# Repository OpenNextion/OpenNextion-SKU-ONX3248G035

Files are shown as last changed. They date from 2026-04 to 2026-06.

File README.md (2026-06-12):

[**English**](./README.md) | [简体中文](./README.zh-CN.md)

# ONX3248G035

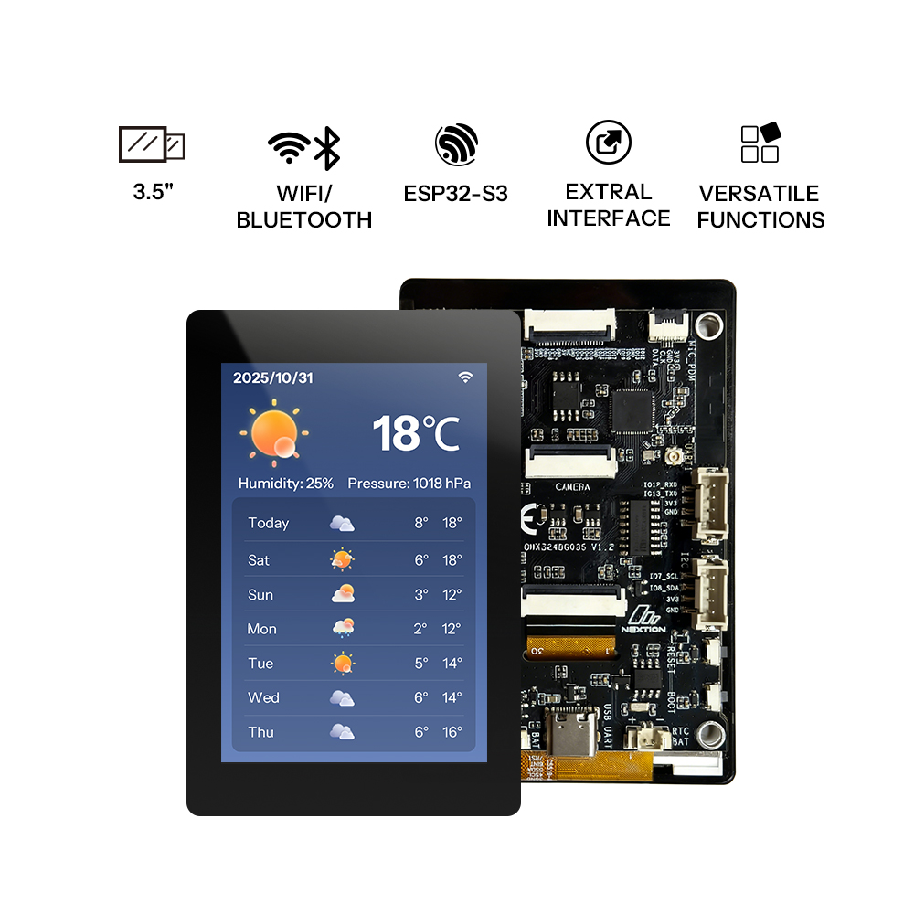
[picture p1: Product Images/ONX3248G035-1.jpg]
ONX3248G035


## Overview

`ONX3248G035` is a 3.5-inch Open Nextion HMI development board based on `ESP32-S3R8`. It integrates a capacitive touch display, `2.4 GHz Wi-Fi`, `Bluetooth 5 LE`, `MicroSD`, camera, microphone, speaker, battery management, and multiple expansion interfaces, making it suitable for HMI panels, IoT terminals, multimedia interaction, and rapid prototyping.

This repository collects product images, mechanical drawings, schematics, PCB files, certification documents, datasheets, USB-to-serial drivers, and example projects for this model. Both `ESP-IDF` and `ESP-Arduino` examples are provided so users can choose the development workflow that best fits their project.

## Purchase Links

- Product: [Open Nextion 3.5" Genius Series ESP32-S3 LCD Touchscreen Development Board](https://itead.cc/product/open-nextion-3-5-genius-series-esp32-s3-lcd-touchscreen-development-board/)
- Optional Audio Accessory: [Nextion BOX Speaker](https://itead.cc/product/nextion-box-speaker/)
- Optional Microphone Accessory: [Nextion Dual MIC Board](https://itead.cc/product/nextion-dual-mic-board/)
- Optional Expansion Accessory: [Nextion IO Adapter V2](https://itead.cc/product/nextion-io-adapter-v2/)

## Hardware Specifications

The following specifications are compiled from the official Wiki and the files included in this repository:

| Item | Specification |
| :--- | :--- |
| Model | `ONX3248G035` |
| MCU | `ESP32-S3R8`, Xtensa LX7 dual-core, up to `240 MHz` |
| Flash | `16 MB` |
| PSRAM | `8 MB` |
| Display Size | `3.5"` |
| Resolution | `320 x 480` |
| Colors | `262K` |
| Brightness | `300 nit` |
| Touch Type | Capacitive touch |
| LCD Driver | `ST7796` |
| Touch Driver | `CST826` |
| Wireless | `2.4 GHz Wi-Fi` + `Bluetooth 5 LE` |
| Power Input | `DC 5V/1A` |
| Battery Support | `3.7V` Li-ion battery interface with charging management, plus `3V` RTC backup battery support |
| Main Interfaces | `USB-C`, Grove `I2C`, Grove `UART1`, `MicroSD`, camera interface, PDM microphone interface, speaker interface, 24-pin GPIO, external antenna connector |
| Operating Temperature | `-20 to 70 C` |
| Storage Temperature | `-30 to 80 C` |
| Weight | Net weight about `61 g`, gross weight about `115 g` |

## Key Features

- Built on `ESP32-S3` for connected applications with graphical user interfaces.
- Onboard `3.5"` capacitive touch display, suitable for control panels, dashboards, and interactive terminals.
- Supports `MicroSD`, camera, `PDM` microphone, and speaker expansion for multimedia and voice-interaction projects.
- `USB-C` is used for power, firmware flashing, and serial logs, and supports automatic download mode.
- Includes an onboard antenna and a reserved external antenna connector for wireless applications.
- Supports Li-ion battery power and RTC backup battery, useful for portable devices and offline-clock scenarios.

## Repository Contents

| Folder | Description |
| :--- | :--- |
| `Certifications/` | Certification and compliance documents |
| `Datasheets/` | Datasheets for key components such as `ESP32-S3`, `ST7796`, `CST826`, `PCF8574`, and `IP4054V` |
| `Drawings/` | Mechanical dimension file, `2D` drawing, and `3D` model |
| `Example Programs/` | Example projects for both `ESP-IDF` and `ESP-Arduino` |
| `LTA Announcement/` | Official announcement document |
| `Product Images/` | Product photos |
| `Schematic & Layout /` | Schematics and PCB layout files |
| `USB-to-Serial Driver/` | USB-to-serial drivers for Windows, macOS, and Linux |

## Example Projects

`Example Programs/` contains two sets of ready-to-use examples:

- `ESP-IDF/`: native ESP-IDF projects, recommended for production firmware, component-based development, and full access to ESP-IDF features.
- `ESP-Arduino/`: Arduino sketches, recommended for quick prototyping, Arduino IDE users, and developers who prefer the ESP32 Arduino core.

Most example folders include both Chinese and English documentation.

### ESP-IDF Examples

| Example Folder | Description |
| :--- | :--- |
| `01_touch_test` | Touch test for LCD and touch verification |
| `02_music_test` | Play audio from `MicroSD` with touch interaction |
| `03_sd_card_image_test` | Read and display images from `MicroSD` |
| `04_sd_card_test` | `MicroSD` mount, read/write, and card info test |
| `05_wifi_test` | Wi-Fi scan, connection, and status display |
| `06_camera_test` | Connect an `OV2640` camera and preview the image on screen |
| `07_microphone_test` | PDM microphone capture, speech front-end processing, and playback |
| `08_battery_test` | Battery voltage, battery level estimation, and charge status display |
| `09_outofbox_demo` | Factory demo for quickly verifying LCD, touch, and LVGL UI |

### ESP-Arduino Examples

`Example Programs/ESP-Arduino/` contains Arduino versions of the board examples. Each folder can be opened directly in Arduino IDE through its `.ino` file.

| Example Folder | Description |
| :--- | :--- |
| `01_touch_test` | LCD, CST826 touch, PCF8574 reset, and LVGL touch-coordinate display test |
| `02_music_test` | Play `.mp3` files from `/music` on `MicroSD` with the LVGL music UI and speaker output |
| `03_sd_card_image_test` | Scan and display `JPG`, `JPEG`, and `PNG` images from `MicroSD` |
| `04_sd_card_test` | `MicroSD` mount, write, read, and verification test using `SD_MMC` |
| `05_wifi_test` | Wi-Fi scanning and connection UI using the ESP32 Arduino `WiFi` library |
| `06_camera_test` | `OV2640` camera capture and live LCD preview |
| `07_microphone_test` | PDM microphone recording and I2S speaker playback |
| `08_battery_test` | Battery voltage sampling, capacity estimation, and charging-state display |
| `09_outofbox_demo` | Arduino port of the factory LVGL widgets demo |

## Quick Start

### 1. Install the Driver

If your computer does not recognize the serial device, install the appropriate driver from `USB-to-Serial Driver/`:

- Windows: `CH340K-USB-to-UART-Driver.zip`
- macOS: `CH341SER_MAC.ZIP`
- Linux: `CH341SER_LINUX.zip`

### 2. Connect the Board

Use a `USB-C` cable to connect the board to your computer. The `USB-C` port can be used for:

- Power supply
- Firmware flashing
- Serial log output

### 3. Choose an Example

Go to `Example Programs/ESP-IDF/` or `Example Programs/ESP-Arduino/` and select the example you need. Check the included `README_zh.md` or `README_en.md` in each example folder and prepare the required peripherals, such as a `MicroSD` card, camera, microphone, or speaker.

### 4. Set Up the Development Environment

For `ESP-IDF`, the included examples indicate:

- Development version: `ESP-IDF 5.4.1`
- Recommended version: `ESP-IDF >= 5.4.0`

For `ESP-Arduino`, install the ESP32 Arduino core and the libraries required by the selected example. The common libraries are:

- `GFX Library for Arduino`
- `Adafruit CST8XX Library`
- `Adafruit PCF8574`
- `lvgl` 8.3.x

Some examples need additional libraries or built-in ESP32 Arduino features, such as `SD_MMC`, `WiFi`, `esp_camera`, ESP-IDF I2S drivers, or `ESP32-audioI2S-master`. See the example-specific README before compiling.

Recommended Arduino IDE settings for the larger examples, such as `02_music_test` and `09_outofbox_demo`:

- Board: `ESP32S3 Dev Module`
- Flash Size: `16MB (128Mb)`
- PSRAM: `OPI PSRAM`
- Partition Scheme: `16M Flash (3MB APP/9.9MB FATFS)`

### 5. Build and Flash with ESP-IDF

Example using the out-of-box demo:

```bash
cd "Example Programs/ESP-IDF/09_outofbox_demo"
idf.py set-target esp32s3
idf.py build
idf.py -p <PORT> flash monitor
```

If flashing fails on the first attempt, hold the `BOOT` button and press `RESET` once to enter download mode, then try again.

### 6. Build and Upload with Arduino

Open the target `.ino` file in Arduino IDE, select an ESP32-S3 board, choose the flash and PSRAM settings, then compile and upload. The same settings can also be supplied through `arduino-cli`. Example:

```bash
arduino-cli compile --fqbn esp32:esp32:esp32s3:FlashSize=16M,PartitionScheme=app3M_fat9M_16MB,PSRAM=opi "Example Programs/ESP-Arduino/09_outofbox_demo"
arduino-cli upload --fqbn esp32:esp32:esp32s3:FlashSize=16M,PartitionScheme=app3M_fat9M_16MB,PSRAM=opi -p <PORT> "Example Programs/ESP-Arduino/09_outofbox_demo"
```

## Notes

- `USB_UART` and `UART0` share the same `TX/RX` signals and cannot be used at the same time.
- The 24-pin GPIO expansion shares signals with `UART1`, `MIC_PDM`, and `CAMERA`, so check pin multiplexing before use.
- `USB-C` supports automatic download mode, while `UART0` does not.
- Wi-Fi supports `2.4 GHz` only.
- The speaker interface supports up to `2W`.
- If you need an external antenna, follow the official hardware instruction to switch the RF path by desoldering the corresponding resistor.
- The board itself is not waterproof. If needed, use a custom enclosure.
- For mechanical dimensions, see `Drawings/ONX3248G035-Dimension.pdf`.
- For detailed circuit design, see the files under `Schematic & Layout /`.

## References

- Official product page: [ONX3248G035 Wiki](https://nextion.tech/wiki/onx3248g035/)
- ESP-IDF getting started: [ESP32-S3 Getting Started](https://docs.espressif.com/projects/esp-idf/en/stable/esp32s3/get-started/)

If you are starting development on this board, it is recommended to begin with `09_outofbox_demo` or `01_touch_test` to verify the screen, touch, and basic environment first, then move on to `Wi-Fi`, `MicroSD`, camera, or audio-related features. Use `ESP-IDF` when you need the complete Espressif framework, and use `ESP-Arduino` when you want a faster Arduino-style starting point.

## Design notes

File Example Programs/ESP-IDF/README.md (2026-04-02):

# ESP32S3-NEXTION-EXAMPLE

This directory contains example projects for the ESP32-S3 development board (ONX3248G035), covering peripherals such as LCD touch, camera, audio, SD card, Wi-Fi, and battery. For details of each example, see the README in the corresponding example folder.

## Purchase Links

- Product: [Open Nextion 3.5" Genius Series ESP32-S3 LCD Touchscreen Development Board](https://itead.cc/product/open-nextion-3-5-genius-series-esp32-s3-lcd-touchscreen-development-board/)
- Optional Audio Accessory: [Nextion BOX Speaker](https://itead.cc/product/nextion-box-speaker/)
- Optional Microphone Accessory: [Nextion Dual MIC Board](https://itead.cc/product/nextion-dual-mic-board/)
- Optional Expansion Accessory: [Nextion IO Adapter V2](https://itead.cc/product/nextion-io-adapter-v2/)

> Note: This project was developed with ESP-IDF 5.4.1. It is recommended to use ESP-IDF version >= 5.4.0

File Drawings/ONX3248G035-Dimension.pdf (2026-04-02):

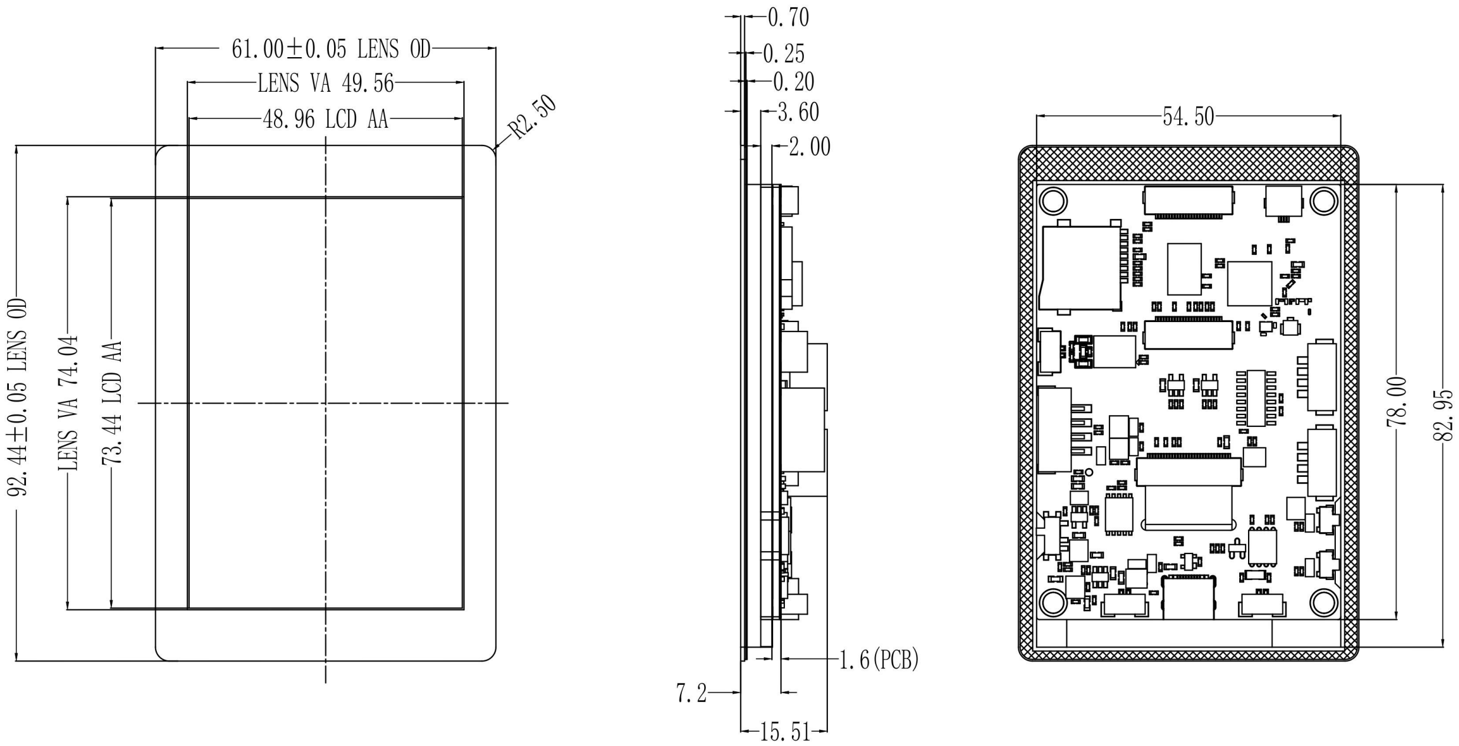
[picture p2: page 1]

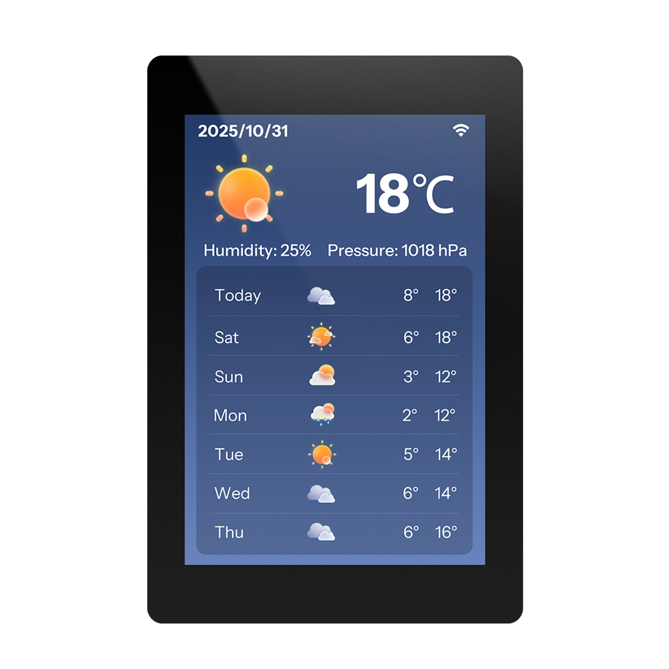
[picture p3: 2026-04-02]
Product Images/ONX3248G035-2.jpg

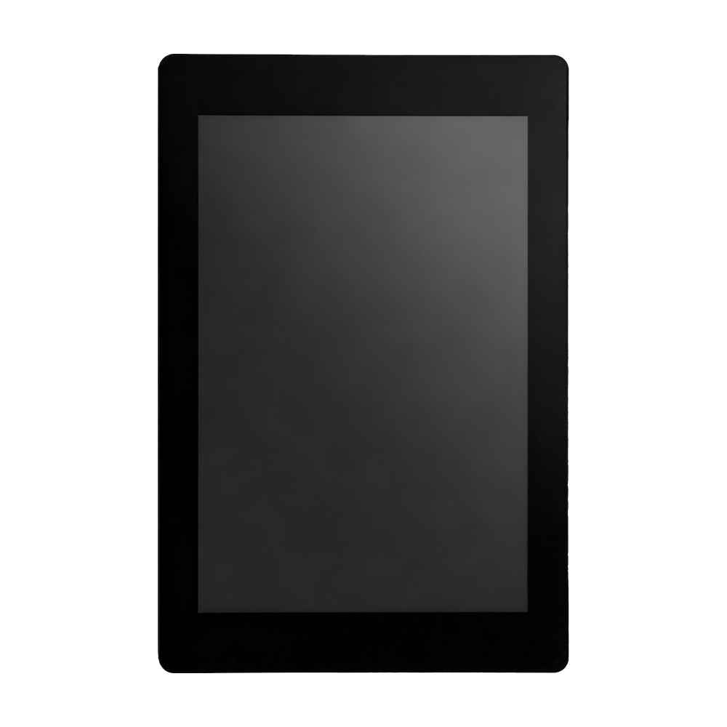
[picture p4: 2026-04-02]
Product Images/ONX3248G035-5.jpg

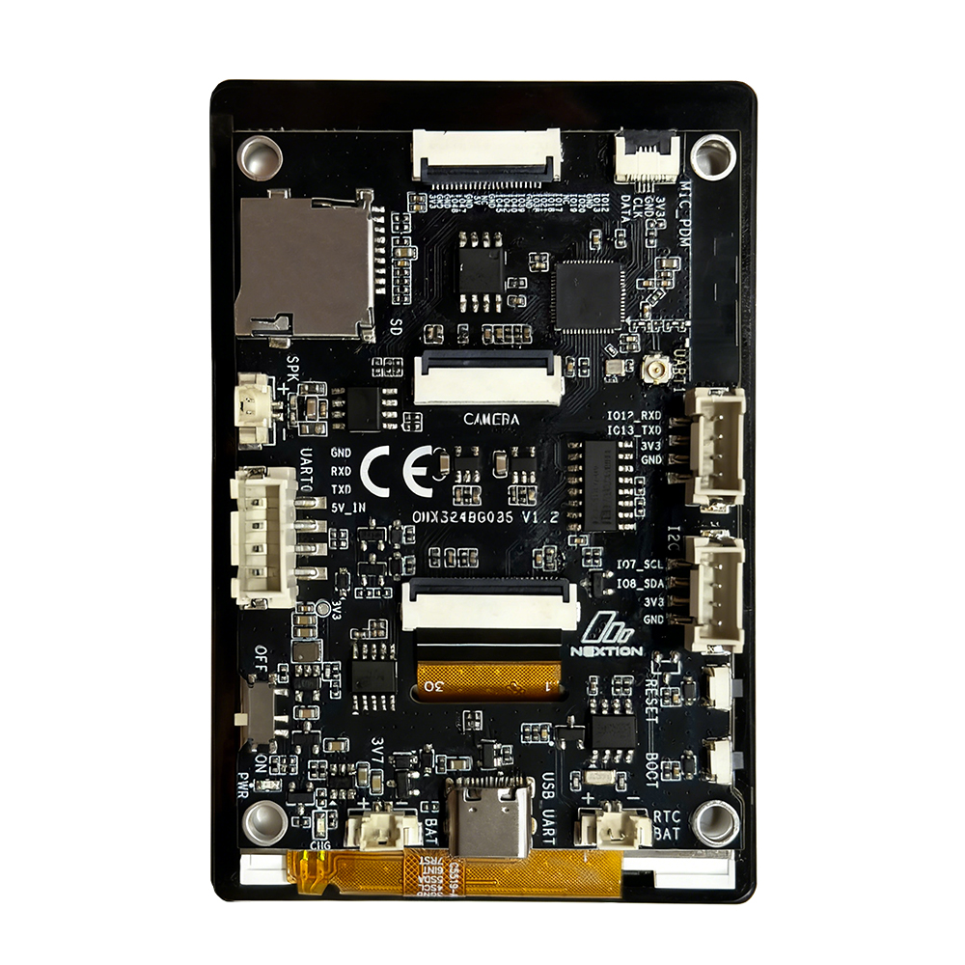
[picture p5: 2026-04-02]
Product Images/ONX3248G035-3.jpg

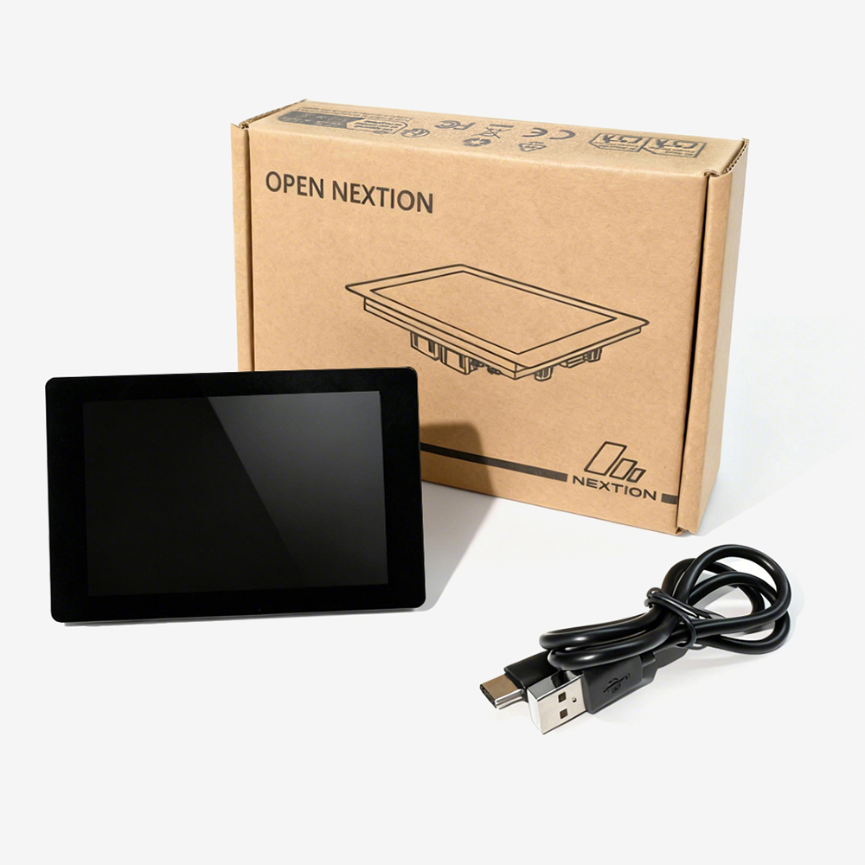
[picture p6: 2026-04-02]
Product Images/ONX3248G035-4.jpg

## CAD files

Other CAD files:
Drawings/ONX3248G035_2D_File.dwg

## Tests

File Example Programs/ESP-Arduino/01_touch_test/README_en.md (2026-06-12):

# ESP32-S3 Arduino Touch Test Example

## Overview

This is the ESP-Arduino version of `01_touch_test` for the ONX3248G035 3.5-inch display board. It uses standard Arduino libraries for the hardware drivers and LVGL for UI rendering:

- LCD: `Arduino_ST7796` from `GFX Library for Arduino`
- Touch: `Adafruit CST8XX Library`
- IO expander: `Adafruit PCF8574`
- UI: `lvgl`

The screen shows a white background and a gray `Touch Test` label. When the panel is touched, the sketch draws a red 4x4 pixel square at the touch position and prints the touch coordinates to the serial monitor.

LVGL renders the UI text. The touch trail follows the ESP-IDF example approach: it draws 4x4 red blocks directly through the LCD driver, avoiding unbounded LVGL object creation during long touch tests.

## Files

- `01_touch_test.ino`: Main sketch, directly openable in Arduino IDE.
- `BoardConfig.h`: Board pins, resolution, and I2C addresses.
- `build_opt.h`: Arduino ESP32 build options used to make LVGL use its built-in default configuration.

## Hardware Pins

| Function | ESP32-S3 Pin |
| :--- | :--- |
| I2C SCL | GPIO7 |
| I2C SDA | GPIO8 |
| LCD SCLK | GPIO5 |
| LCD MOSI | GPIO1 |
| LCD DC | GPIO3 |
| LCD CS | GPIO2 |
| LCD BL | GPIO6 |
| LCD RST | PCF8574 P6 |

## Arduino IDE Setup

1. Install the ESP32 Arduino core.
2. Install these libraries: `GFX Library for Arduino`, `Adafruit CST8XX Library`, `Adafruit PCF8574`, and `lvgl`.
3. Open `ESP-Arduino/01_touch_test/01_touch_test.ino`.
4. Select an ESP32-S3 board.
5. Recommended settings:
   - USB CDC On Boot: Enabled
   - PSRAM: Enabled
   - Flash Size: select the option that matches the module
6. Compile and upload.
7. Open the serial monitor at 115200 baud to view touch coordinates.

## Display Direction

The display direction can be configured at the top of `01_touch_test.ino`:

```cpp
#define DISPLAY_SWAP_XY false
#define DISPLAY_MIRROR_X true
#define DISPLAY_MIRROR_Y false
```

The default values match the ESP-IDF example direction configuration.

## Implementation Notes

- LCD reset is controlled by PCF8574 P6. Other expander pins are kept high during reset to avoid disturbing shared peripherals.
- LVGL renders the initial UI and label. Root-screen scrolling is disabled so edge touches do not drag the page.
- Touch dots are drawn directly with `Arduino_GFX`, similar to the ESP-IDF example's `esp_lcd_panel_draw_bitmap()` path.

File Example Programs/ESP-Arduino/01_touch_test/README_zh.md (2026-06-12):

# ESP32-S3 Arduino 触摸测试示例

## 概述

本示例是 `01_touch_test` 的 ESP-Arduino 版本，用于 ONX3248G035 开发板的 3.5 寸屏基础触摸测试。程序使用 Arduino 标准库生态完成硬件驱动和 UI 绘制：

- LCD：`GFX Library for Arduino` 的 `Arduino_ST7796`
- 触摸：`Adafruit CST8XX Library`
- IO 扩展：`Adafruit PCF8574`
- UI：`lvgl`

屏幕显示白色背景和灰色 `Touch Test` 文本。触摸屏幕时，程序会在触点位置绘制红色 4x4 像素方块，并在串口监视器输出触摸坐标。

UI 文本由 LVGL 绘制；触摸轨迹参考 ESP-IDF 例程的实现方式，使用 LCD 驱动直接刷 4x4 红色小块，避免连续触摸时创建大量 LVGL 对象导致内存增长。

## 文件

- `01_touch_test.ino`: Arduino IDE 可直接打开的主程序。
- `BoardConfig.h`: 板级引脚、分辨率和 I2C 地址配置。
- `build_opt.h`: Arduino ESP32 编译选项，用于让 LVGL 使用内置默认配置。

## 硬件引脚

| 功能 | ESP32-S3 引脚 |
| :--- | :--- |
| I2C SCL | GPIO7 |
| I2C SDA | GPIO8 |
| LCD SCLK | GPIO5 |
| LCD MOSI | GPIO1 |
| LCD DC | GPIO3 |
| LCD CS | GPIO2 |
| LCD BL | GPIO6 |
| LCD RST | PCF8574 P6 |

## Arduino IDE 设置

1. 安装 ESP32 Arduino core。
2. 安装库：`GFX Library for Arduino`、`Adafruit CST8XX Library`、`Adafruit PCF8574`、`lvgl`。
3. 打开 `ESP-Arduino/01_touch_test/01_touch_test.ino`。
4. 开发板选择 ESP32-S3 类型的开发板。
5. 建议设置：
   - USB CDC On Boot: Enabled
   - PSRAM: Enabled
   - Flash Size: 按实际模组选项选择
6. 编译并烧录。
7. 打开 115200 波特率串口监视器查看触摸坐标。

## 屏幕方向

屏幕方向可在 `01_touch_test.ino` 顶部通过以下宏配置：

```cpp
#define DISPLAY_SWAP_XY false
#define DISPLAY_MIRROR_X true
#define DISPLAY_MIRROR_Y false
```

当前默认值与 ESP-IDF 例程中的方向配置保持一致。

## 实现说明

- LCD 复位通过 PCF8574 P6 控制，初始化时保持其它扩展 IO 为高电平，避免影响共用扩展 IO 的外设。
- LVGL 负责初始界面和文字显示，根页面禁用滚动，避免触摸边缘时页面被拖动。
- 红点使用 `Arduino_GFX` 直接刷屏绘制，行为接近 ESP-IDF 例程中的 `esp_lcd_panel_draw_bitmap()`。

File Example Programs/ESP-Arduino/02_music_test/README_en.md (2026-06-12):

# ESP32-S3 Arduino Music Test Example

## Overview

This is the ESP-Arduino version of `02_music_test` for the ONX3248G035 board.

It uses standard Arduino/ESP32 libraries and third-party libraries:

- LCD: `Arduino_ST7796` from `GFX Library for Arduino`
- Touch: `Adafruit CST8XX Library`
- IO expander: `Adafruit PCF8574`
- SD card: `SD_MMC` from the ESP32 Arduino core
- UI: `lvgl`, with the Music Demo UI assets ported from the ESP-IDF `components/gui`
- Audio playback: `ESP32-audioI2S-master`

The sketch mounts the SD card, scans `/music` for `.mp3` files, and displays the same LVGL Music Demo style as the ESP-IDF example: cover art, spectrum, track metadata, playback controls, and the ALL TRACKS list. Tapping a track plays it through the onboard NS4168 speaker amplifier.

## Notes

This Arduino version matches the ESP-IDF UI and uses a proven third-party library for MP3 decoding and I2S playback. It does not implement a custom audio decoder.

## Audio And Pop Suppression

- I2S BCLK: GPIO14
- I2S LRCLK/WS: GPIO16
- I2S DOUT/SDATA: GPIO15
- NS4168 enable: PCF8574 `I2S_CTRL`

PCF8574 ports default high after power-up. If `I2S_CTRL` is enabled too early, the speaker may pop before I2S output is stable. This sketch keeps `I2S_CTRL=LOW` during initialization and enables the amplifier only after MP3 decoding and I2S output have started. It also disables the amplifier during pause and track switching.

## ESP32S3R8 + 16 MB Flash Settings

This sketch ports the complete LVGL Music UI images and fonts from the ESP-IDF example, so it is larger than Arduino's default `1.2 MB APP` partition. For ESP32S3R8 with external 16 MB flash, use these Arduino IDE settings:

- Board: `ESP32S3 Dev Module`
- Flash Size: `16MB (128Mb)`
- PSRAM: `OPI PSRAM`
- Partition Scheme: `16M Flash (3MB APP/9.9MB FATFS)`

The project includes `sketch.yaml` as a record of the target board settings. With the current Arduino CLI, `--profile` may skip the locally installed library search path, so use the verified full FQBN:

```bash
arduino-cli compile --fqbn esp32:esp32:esp32s3:FlashSize=16M,PartitionScheme=app3M_fat9M_16MB,PSRAM=opi ESP-Arduino/02_music_test
arduino-cli upload --fqbn esp32:esp32:esp32s3:FlashSize=16M,PartitionScheme=app3M_fat9M_16MB,PSRAM=opi -p <your port> ESP-Arduino/02_music_test
```

## Files

- `02_music_test.ino`: Main Arduino sketch.
- `BoardConfig.h`: Board pins, resolution, I2C addresses, SD pins, and I2S pins.
- `build_opt.h`: LVGL build option.
- `sketch.yaml`: Target board setting record for ESP32S3R8 + 16 MB flash.
- `src/gui`: LVGL Music UI source and assets ported from the ESP-IDF example.
- `src/gui/gui_hal.cpp`: Arduino adapter for SD_MMC scanning, MP3 playback, volume mapping, and amplifier timing.

## SD Card Layout

Create this folder in the SD card root:

```text
/music
```

Then copy `.mp3` files into it.

## Dependencies

Install these libraries from Arduino IDE Library Manager:

- `GFX Library for Arduino`
- `Adafruit CST8XX Library`
- `Adafruit PCF8574`
- `lvgl` 8.3.x
- `ESP32-audioI2S-master`

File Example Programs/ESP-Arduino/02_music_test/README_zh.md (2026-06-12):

# ESP32-S3 Arduino 音乐测试示例

## 概述

本示例是 `02_music_test` 的 ESP-Arduino 版本，用于 ONX3248G035 开发板的基础音乐文件测试。

程序使用标准 Arduino/ESP32 库和第三方库：

- LCD：`GFX Library for Arduino` 的 `Arduino_ST7796`
- 触摸：`Adafruit CST8XX Library`
- IO 扩展：`Adafruit PCF8574`
- SD 卡：ESP32 Arduino core 的 `SD_MMC`
- UI：`lvgl`，并移植 ESP-IDF 版本 `components/gui` 的 Music Demo 界面资源
- 音频播放：`ESP32-audioI2S-master`

示例会挂载 SD 卡，扫描 `/music` 目录中的 `.mp3` 文件，并使用与 ESP-IDF 版本同源的 LVGL Music Demo UI 显示封面、波形、曲目信息、播放控制和 ALL TRACKS 列表。点击曲目后会通过 I2S 输出到板载 NS4168 喇叭功放。

## 说明

当前 Arduino 版本已对齐 ESP-IDF 版本的 UI 效果，并使用成熟第三方库完成 MP3 解码和 I2S 播放，没有自写音频解码器。

## 音频与防爆破声

- I2S BCLK: GPIO14
- I2S LRCLK/WS: GPIO16
- I2S DOUT/SDATA: GPIO15
- NS4168 使能：PCF8574 `I2S_CTRL`

PCF8574 上电默认端口为高电平，若过早打开 `I2S_CTRL`，喇叭可能在 I2S 输出稳定前产生瞬间爆破声。本例程在初始化时保持 `I2S_CTRL=LOW`，只有在 MP3 解码和 I2S 输出启动后延迟打开功放；暂停或切歌时也会先关闭功放。

## ESP32S3R8 + 16MB Flash 配置

本例程移植了 ESP-IDF 版本的完整 LVGL Music UI 图片和字体资源，程序体积超过 Arduino 默认 `1.2MB APP` 分区。你的硬件为 ESP32S3R8 + 外挂 16MB Flash，请在 Arduino IDE 中选择：

- Board: `ESP32S3 Dev Module`
- Flash Size: `16MB (128Mb)`
- PSRAM: `OPI PSRAM`
- Partition Scheme: `16M Flash (3MB APP/9.9MB FATFS)`

工程内提供了 `sketch.yaml` 记录目标配置。当前 Arduino CLI 版本使用 `--profile` 时可能不加载本机已安装库路径，推荐使用已验证的完整 FQBN：

```bash
arduino-cli compile --fqbn esp32:esp32:esp32s3:FlashSize=16M,PartitionScheme=app3M_fat9M_16MB,PSRAM=opi ESP-Arduino/02_music_test
arduino-cli upload --fqbn esp32:esp32:esp32s3:FlashSize=16M,PartitionScheme=app3M_fat9M_16MB,PSRAM=opi -p <你的串口> ESP-Arduino/02_music_test
```

## 文件

- `02_music_test.ino`: Arduino 主程序。
- `BoardConfig.h`: 板级引脚、分辨率、I2C 地址和 SD/I2S 引脚配置。
- `build_opt.h`: LVGL 编译选项。
- `sketch.yaml`: ESP32S3R8 + 16MB Flash 的目标配置记录。
- `src/gui`: 从 ESP-IDF 版本移植的 LVGL Music UI 源码和资源。
- `src/gui/gui_hal.cpp`: Arduino 适配层，负责 SD_MMC 扫描、MP3 播放、音量映射和功放时序控制。

## SD 卡目录

请在 SD 卡根目录创建：

```text
/music
```

并放入 `.mp3` 文件。

## 依赖库

请在 Arduino IDE 的 Library Manager 中安装：

- `GFX Library for Arduino`
- `Adafruit CST8XX Library`
- `Adafruit PCF8574`
- `lvgl` 8.3.x
- `ESP32-audioI2S-master`

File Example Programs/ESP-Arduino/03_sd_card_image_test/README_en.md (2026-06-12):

# ESP32-S3 Arduino SD Card Image Test Example

## Overview

This is the ESP-Arduino version of `03_sd_card_image_test`. It tests SD-card image-file scanning and full-screen image browsing.

Libraries used:

- LCD: `GFX Library for Arduino`
- Touch: `Adafruit CST8XX Library`
- IO expander: `Adafruit PCF8574`
- SD card: `SD_MMC` from the ESP32 Arduino core
- UI: `lvgl`
- JPG/JPEG decoding: Espressif JPEG decoder bundled with the ESP32 Arduino core
- PNG decoding: LVGL bundled `lodepng`

The sketch scans `/images` for image files. When images are found, it opens a full-screen image viewer. Swipe left/right to switch to the previous or next image.

## Notes

This version does not implement a custom image decoder. JPG/JPEG files are decoded with `esp_jpeg_decode()` from the ESP32 Arduino core, and PNG files are decoded with LVGL's bundled `lodepng`. Images are fully decoded into a PSRAM frame buffer before the LCD is updated in bands, which avoids visible top-to-bottom decode refresh on the panel.

Images use a fixed width-fit policy: regardless of the source orientation, the image is scaled to the 320-pixel screen width and vertically centered. Other extensions are scanned for compatibility with the ESP-IDF directory rules, but the current Arduino version directly renders JPG/JPEG/PNG only; unsupported formats show a decode-failed message.

`build_opt.h` enables `LV_USE_PNG` and `LV_MEM_CUSTOM` so LVGL builds PNG support and the PNG decoder can allocate from the configured external-memory path.

## SD Card Layout

Create this folder in the SD card root:

```text
/images
```

Then copy image files into it.

Recommended formats:

```text
.jpg
.jpeg
.png
```

## Arduino IDE Settings

When opening this example in Arduino IDE, use:

- Board: `ESP32S3 Dev Module`
- Flash Size: `16MB (128Mb)`
- PSRAM: `OPI PSRAM`
- Partition Scheme: `16M Flash (3MB APP/9.9MB FATFS)`

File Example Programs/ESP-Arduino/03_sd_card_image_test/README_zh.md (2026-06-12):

# ESP32-S3 Arduino SD 卡图片测试示例

## 概述

本示例是 `03_sd_card_image_test` 的 ESP-Arduino 版本，用于测试 SD 卡图片文件扫描和全屏图片浏览。

使用的库：

- LCD：`GFX Library for Arduino`
- 触摸：`Adafruit CST8XX Library`
- IO 扩展：`Adafruit PCF8574`
- SD 卡：ESP32 Arduino core 的 `SD_MMC`
- UI：`lvgl`
- JPG/JPEG 解码：ESP32 Arduino core 内置的 Espressif JPEG decoder
- PNG 解码：LVGL 内置 `lodepng`

程序会扫描 SD 卡 `/images` 目录中的图片文件。找到图片后会进入全屏图片浏览界面，左右滑动切换上一张/下一张。

## 说明

当前版本不自写图片解码器，JPG/JPEG 使用 ESP32 Arduino core 提供的 `esp_jpeg_decode()`，PNG 使用 LVGL 自带的 `lodepng`。图片会先完整解码到 PSRAM 帧缓冲，再一次性分段刷新到 LCD，避免屏幕出现明显的从上到下解码刷新过程。

图片显示策略为固定宽度适配：无论图片原始方向如何，都会按屏幕宽度缩放到 320 像素宽，并在垂直方向居中显示。其他扩展名会参与扫描以兼容 ESP-IDF 版本的目录规则，但 Arduino 版本当前只直接渲染 JPG/JPEG/PNG；遇到暂未支持的格式时屏幕会显示解码失败提示。

`build_opt.h` 中启用了 `LV_USE_PNG` 和 `LV_MEM_CUSTOM`，用于让 LVGL 编译 PNG 支持，并让 PNG 解码输出使用可用的外部内存配置。

## SD 卡目录

请在 SD 卡根目录创建：

```text
/images
```

并放入图片文件。

推荐优先放入：

```text
.jpg
.jpeg
.png
```

## Arduino IDE 设置

使用 Arduino IDE 打开本例程时，开发板建议选择：

- Board: `ESP32S3 Dev Module`
- Flash Size: `16MB (128Mb)`
- PSRAM: `OPI PSRAM`
- Partition Scheme: `16M Flash (3MB APP/9.9MB FATFS)`

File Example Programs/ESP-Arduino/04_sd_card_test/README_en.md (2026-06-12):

# ESP32-S3 Arduino SD Card Test Example

## Overview

This is the ESP-Arduino version of `04_sd_card_test`. It tests SD-card mounting, writing, reading, and verification.

Libraries used:

- LCD: `GFX Library for Arduino`
- Touch: `Adafruit CST8XX Library`
- IO expander: `Adafruit PCF8574`
- SD card: `SD_MMC` from the ESP32 Arduino core
- UI: `lvgl`

After tapping the `SD CARD TEST` button, the sketch re-detects and mounts the SD card, writes `/SD CARD TEST.txt` to the SD card root, reads it back, and compares the content. It shows `WRITE SUCCESS` when the readback matches, `NO SD CARD DETECTED` when no card is present, and an error message for other read/write failures.

## Test Flow

1. Initialize the LCD, CST826 touch controller, PCF8574 IO expander, and LVGL.
2. Tap the `SD CARD TEST` button.
3. Release the previous `SD_MMC` mount state and mount the SD card again.
4. Write a random string to `/SD CARD TEST.txt`.
5. Close the file, reopen it, and read the content back.
6. Compare the written and readback strings, then show the result on screen.

With this flow, removing the SD card after one successful test is handled on the next tap and shows `NO SD CARD DETECTED`.

## SD Card Notes

- The sketch uses `SD_MMC` from the ESP32 Arduino core in 1-bit mode.
- `/SD CARD TEST.txt` is created or overwritten in the SD card root.
- The file content is similar to `SD CARD TEST RAND NUM 12345678` and changes on every tap.

## Arduino IDE Settings

When opening this example in Arduino IDE, use:

- Board: `ESP32S3 Dev Module`
- Flash Size: `16MB (128Mb)`
- PSRAM: `OPI PSRAM`
- Partition Scheme: `16M Flash (3MB APP/9.9MB FATFS)`

## Files

- `04_sd_card_test.ino`: Main Arduino sketch.
- `BoardConfig.h`: Board pins, resolution, and SD-card pins.
- `build_opt.h`: LVGL build option; it currently skips the default `lv_conf.h`.

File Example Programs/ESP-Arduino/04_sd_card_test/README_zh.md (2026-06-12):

# ESP32-S3 Arduino SD 卡读写测试示例

## 概述

本示例是 `04_sd_card_test` 的 ESP-Arduino 版本，用于测试 SD 卡挂载、写入、读回和校验。

使用的库：

- LCD：`GFX Library for Arduino`
- 触摸：`Adafruit CST8XX Library`
- IO 扩展：`Adafruit PCF8574`
- SD 卡：ESP32 Arduino core 的 `SD_MMC`
- UI：`lvgl`

点击屏幕上的 `SD CARD TEST` 按钮后，程序会先重新检测并挂载 SD 卡，然后向 SD 卡根目录写入 `/SD CARD TEST.txt`，再读回内容并比较。如果一致，显示 `WRITE SUCCESS`；如果未检测到 SD 卡，显示 `NO SD CARD DETECTED`；其他读写异常显示错误信息。

## 测试流程

1. 初始化 LCD、CST826 触摸、PCF8574 IO 扩展和 LVGL。
2. 点击 `SD CARD TEST` 按钮。
3. 释放上一次的 `SD_MMC` 挂载状态，并重新挂载 SD 卡。
4. 写入随机字符串到 `/SD CARD TEST.txt`。
5. 关闭文件后重新打开并读回内容。
6. 比较写入和读回内容，并在屏幕上显示测试结果。

这样处理后，插卡测试成功后再拔卡，下一次点击会重新检测 SD 卡并显示 `NO SD CARD DETECTED`。

## SD 卡说明

- 使用 ESP32 Arduino core 的 `SD_MMC`，配置为 1-bit 模式。
- SD 卡根目录会生成或覆盖 `/SD CARD TEST.txt`。
- 测试文件内容类似 `SD CARD TEST RAND NUM 12345678`，每次点击都会更新。

## Arduino IDE 设置

使用 Arduino IDE 打开本例程时，开发板建议选择：

- Board: `ESP32S3 Dev Module`
- Flash Size: `16MB (128Mb)`
- PSRAM: `OPI PSRAM`
- Partition Scheme: `16M Flash (3MB APP/9.9MB FATFS)`

## 文件

- `04_sd_card_test.ino`: Arduino 主程序。
- `BoardConfig.h`: 板级引脚、分辨率和 SD 卡引脚配置。
- `build_opt.h`: LVGL 编译选项，当前仅跳过默认 `lv_conf.h`。

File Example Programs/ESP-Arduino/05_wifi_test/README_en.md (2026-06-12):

# ESP32-S3 Arduino WiFi Test Example

## Overview

This is the ESP-Arduino version of `05_wifi_test`. It tests WiFi scanning and a basic connection UI.

Libraries used:

- LCD: `GFX Library for Arduino`
- Touch: `Adafruit CST8XX Library`
- IO expander: `Adafruit PCF8574`
- WiFi: `WiFi` from the ESP32 Arduino core
- UI: `lvgl`

Tap `Scan` to scan nearby WiFi APs. The list shows SSID, RSSI, and encryption state. Tap an AP to open the password panel, then tap `Connect` to start the connection attempt.

## Implementation

WiFi scanning and connection use the standard ESP32 Arduino `WiFi.h` APIs. No custom WiFi manager stack is implemented.

## Operation Flow

1. Power on and enter the WiFi Test page.
2. Tap `Scan` in the top-right corner. The sketch switches to STA mode and scans nearby APs.
3. The list shows up to 20 APs. Each item includes SSID, RSSI, and `open` / `secure` state.
4. Tap an AP to open the password panel.
5. Tap the password field to show LVGL's built-in keyboard.
6. Enter the password and tap `Connect` to start connecting.
7. When connected, the status label shows the SSID and IP address. Failed or disconnected states are also shown.

## Notes

- This example demonstrates scanning and basic connection only; WiFi credentials are not saved.
- For open networks, tap the AP and then tap `Connect` with an empty password field.
- The sketch calls `WiFi.disconnect(true)` before scanning so scan results and connection state are refreshed.

## Arduino IDE Settings

When opening this example in Arduino IDE, use:

- Board: `ESP32S3 Dev Module`
- Flash Size: `16MB (128Mb)`
- PSRAM: `OPI PSRAM`
- Partition Scheme: `16M Flash (3MB APP/9.9MB FATFS)`

## Files

- `05_wifi_test.ino`: Main Arduino sketch.
- `BoardConfig.h`: Board pins, resolution, touch, and LCD configuration.
- `build_opt.h`: LVGL build option; it currently skips the default `lv_conf.h`.

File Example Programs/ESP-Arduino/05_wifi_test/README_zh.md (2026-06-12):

# ESP32-S3 Arduino WiFi 测试示例

## 概述

本示例是 `05_wifi_test` 的 ESP-Arduino 版本，用于测试 WiFi 扫描和基础连接 UI。

使用的库：

- LCD：`GFX Library for Arduino`
- 触摸：`Adafruit CST8XX Library`
- IO 扩展：`Adafruit PCF8574`
- WiFi：ESP32 Arduino core 的 `WiFi`
- UI：`lvgl`

点击 `Scan` 按钮后，程序会扫描附近 WiFi AP，并显示 SSID、RSSI 和加密状态。点击某个 AP 后会弹出密码输入框，输入密码并点击 `Connect` 可尝试连接。

## 说明

WiFi 扫描和连接使用 ESP32 Arduino core 的标准 `WiFi.h`，没有自写 WiFi 管理栈。

## 操作流程

1. 上电后进入 WiFi Test 页面。
2. 点击右上角 `Scan`，程序切换到 STA 模式并扫描附近 AP。
3. 列表最多显示 20 个 AP，每一项包含 SSID、RSSI 和 `open` / `secure` 状态。
4. 点击 AP 后弹出密码输入面板。
5. 点击密码输入框会显示 LVGL 内置键盘。
6. 输入密码并点击 `Connect` 后开始连接。
7. 连接成功时显示当前 SSID 和 IP 地址；连接失败或断开时显示对应状态。

## 注意事项

- 本例程只演示扫描和基础连接，不保存 WiFi 配置。
- 开放网络可直接点击 AP 后点击 `Connect`，密码框可以留空。
- 扫描前会调用 `WiFi.disconnect(true)`，用于刷新扫描结果和连接状态。

## Arduino IDE 设置

使用 Arduino IDE 打开本例程时，开发板建议选择：

- Board: `ESP32S3 Dev Module`
- Flash Size: `16MB (128Mb)`
- PSRAM: `OPI PSRAM`
- Partition Scheme: `16M Flash (3MB APP/9.9MB FATFS)`

## 文件

- `05_wifi_test.ino`: Arduino 主程序。
- `BoardConfig.h`: 板级引脚、分辨率和触摸/LCD 配置。
- `build_opt.h`: LVGL 编译选项，当前仅跳过默认 `lv_conf.h`。

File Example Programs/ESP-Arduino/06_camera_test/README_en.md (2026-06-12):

# ESP32-S3 Arduino Camera Test Example

## Overview

This is the ESP-Arduino version of `06_camera_test`. It tests camera capture and live LCD preview on the ONX3248G035 board.

Libraries used:

- LCD: `GFX Library for Arduino`
- Touch: `Adafruit CST8XX Library`
- IO expander: `Adafruit PCF8574`
- UI: `lvgl`
- Camera: `esp_camera` from the ESP32 Arduino core

## Features

- ST7796U display through Arduino_GFX.
- CST826 touch through Adafruit CST8XX.
- LVGL title and status label.
- RGB565/QVGA camera capture through the ESP32 Arduino core camera driver.
- Camera frames are pushed directly to the LCD preview area with Arduino_GFX to reduce per-frame copies.

## Runtime Flow

1. Initialize I2C, PCF8574, LCD, backlight, and touch.
2. Pull camera `PWDN` low through PCF8574 to wake the camera module.
3. Initialize `esp_camera` with QVGA `320x240` and `RGB565` output.
4. Draw the `Camera Test` title and status text with LVGL.
5. In the main loop, capture one frame about every 80 ms and draw it in the middle of the screen.

## Camera Configuration

- Frame size: `FRAMESIZE_QVGA`
- Resolution: `320x240`
- Pixel format: `PIXFORMAT_RGB565`
- XCLK: `20 MHz`
- Uses two frame buffers when PSRAM is available; otherwise falls back to one DRAM frame buffer.

This example matches the ESP-IDF behavior: after boot, it continuously displays the camera preview and does not provide a pause/resume button.

## Arduino IDE Settings

When opening this example in Arduino IDE, use:

- Board: `ESP32S3 Dev Module`
- Flash Size: `16MB (128Mb)`
- PSRAM: `OPI PSRAM`
- Partition Scheme: `16M Flash (3MB APP/9.9MB FATFS)`

## Files

- `06_camera_test.ino`: Main Arduino sketch.
- `BoardConfig.h`: LCD, touch, PCF8574, and camera pin configuration.
- `build_opt.h`: LVGL build option; it currently skips the default `lv_conf.h`.

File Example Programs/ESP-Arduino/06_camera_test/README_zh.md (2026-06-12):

# ESP32-S3 Arduino 摄像头测试示例

## 概述

本示例是 `06_camera_test` 的 ESP-Arduino 版本，用于测试 ONX3248G035 的摄像头采集和 LCD 实时预览。

使用的库：

- LCD：`GFX Library for Arduino`
- 触摸：`Adafruit CST8XX Library`
- IO 扩展：`Adafruit PCF8574`
- UI：`lvgl`
- 摄像头：ESP32 Arduino core 自带 `esp_camera`

## 功能

- 使用 Arduino_GFX 驱动 ST7796U LCD。
- 使用 Adafruit CST8XX 读取 CST826 触摸。
- 使用 LVGL 绘制标题和状态提示。
- 使用 ESP32 Arduino core 自带的 `esp_camera` 获取 RGB565/QVGA 图像。
- 摄像头帧通过 Arduino_GFX 直接刷新到屏幕预览区域，减少每帧复制。

## 运行流程

1. 初始化 I2C、PCF8574、LCD、背光和触摸。
2. 通过 PCF8574 拉低摄像头 `PWDN`，唤醒摄像头模组。
3. 初始化 `esp_camera`，配置为 QVGA `320x240`、`RGB565` 输出。
4. 使用 LVGL 绘制 `Camera Test` 标题和状态文本。
5. 主循环中约每 80 ms 获取一帧摄像头图像，并显示在屏幕中部。

## 摄像头配置

- 帧尺寸：`FRAMESIZE_QVGA`
- 分辨率：`320x240`
- 像素格式：`PIXFORMAT_RGB565`
- XCLK：`20 MHz`
- PSRAM 可用时使用 2 个帧缓冲；否则使用 1 个 DRAM 帧缓冲。

本例程行为与 ESP-IDF 版本保持一致：上电后持续显示摄像头预览，不提供暂停/恢复按钮。

## Arduino IDE 设置

使用 Arduino IDE 打开本例程时，开发板建议选择：

- Board: `ESP32S3 Dev Module`
- Flash Size: `16MB (128Mb)`
- PSRAM: `OPI PSRAM`
- Partition Scheme: `16M Flash (3MB APP/9.9MB FATFS)`

## 文件

- `06_camera_test.ino`: Arduino 主程序。
- `BoardConfig.h`: LCD、触摸、PCF8574 和摄像头引脚配置。
- `build_opt.h`: LVGL 编译选项，当前仅跳过默认 `lv_conf.h`。

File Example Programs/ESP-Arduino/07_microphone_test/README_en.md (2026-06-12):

# ESP32-S3 Arduino Microphone Record/Playback Example

## Overview

This is the ESP-Arduino version of `07_microphone_test`. It tests PDM microphone recording and speaker playback on the ONX3248G035 board.

The interaction matches the ESP-IDF example: press and hold `MIC` to record, release it to loop-play the audio stored in RAM, and tap `Stop` to stop recording or playback.

Libraries used:

- LCD: `GFX Library for Arduino`
- Touch: `Adafruit CST8XX Library`
- IO expander: `Adafruit PCF8574`
- UI: `lvgl`
- Microphone: ESP-IDF `driver/i2s_pdm.h` from the ESP32 Arduino core
- Speaker: ESP-IDF `driver/i2s_std.h` from the ESP32 Arduino core

## Runtime Flow

1. Initialize LCD, CST826 touch, PCF8574, PDM microphone input, and I2S speaker output.
2. Allocate a 30-second recording buffer from PSRAM.
3. Press and hold `MIC`: recording starts and the button turns red.
4. Release `MIC`: recording stops and loop playback starts; the button turns green.
5. Tap `Stop`: stop recording or playback and disable the speaker amplifier.

## Audio Configuration

- Sample rate: `16000 Hz`
- Bit depth: `16-bit`
- Recording format: PDM RX converted to PCM mono
- Playback format: I2S STD TX mono
- Maximum record time: `30 s`
- Record buffer: PSRAM first, internal RAM fallback

Note: the ESP-IDF version includes the ESP-SR/AFE processing chain. The Arduino version keeps the core record/playback behavior and uses the standard I2S drivers bundled with the ESP32 Arduino core instead of porting ESP-SR/AFE.

## Arduino IDE Settings

When opening this example in Arduino IDE, use:

- Board: `ESP32S3 Dev Module`
- Flash Size: `16MB (128Mb)`
- PSRAM: `OPI PSRAM`
- Partition Scheme: `16M Flash (3MB APP/9.9MB FATFS)`

## Files

- `07_microphone_test.ino`: Main Arduino sketch.
- `BoardConfig.h`: LCD, touch, PDM microphone, I2S speaker, and PCF8574 pin configuration.
- `build_opt.h`: LVGL build option; it currently skips the default `lv_conf.h`.

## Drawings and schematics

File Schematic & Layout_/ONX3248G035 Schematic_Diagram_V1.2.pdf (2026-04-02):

# SD CARD ESP32-S3

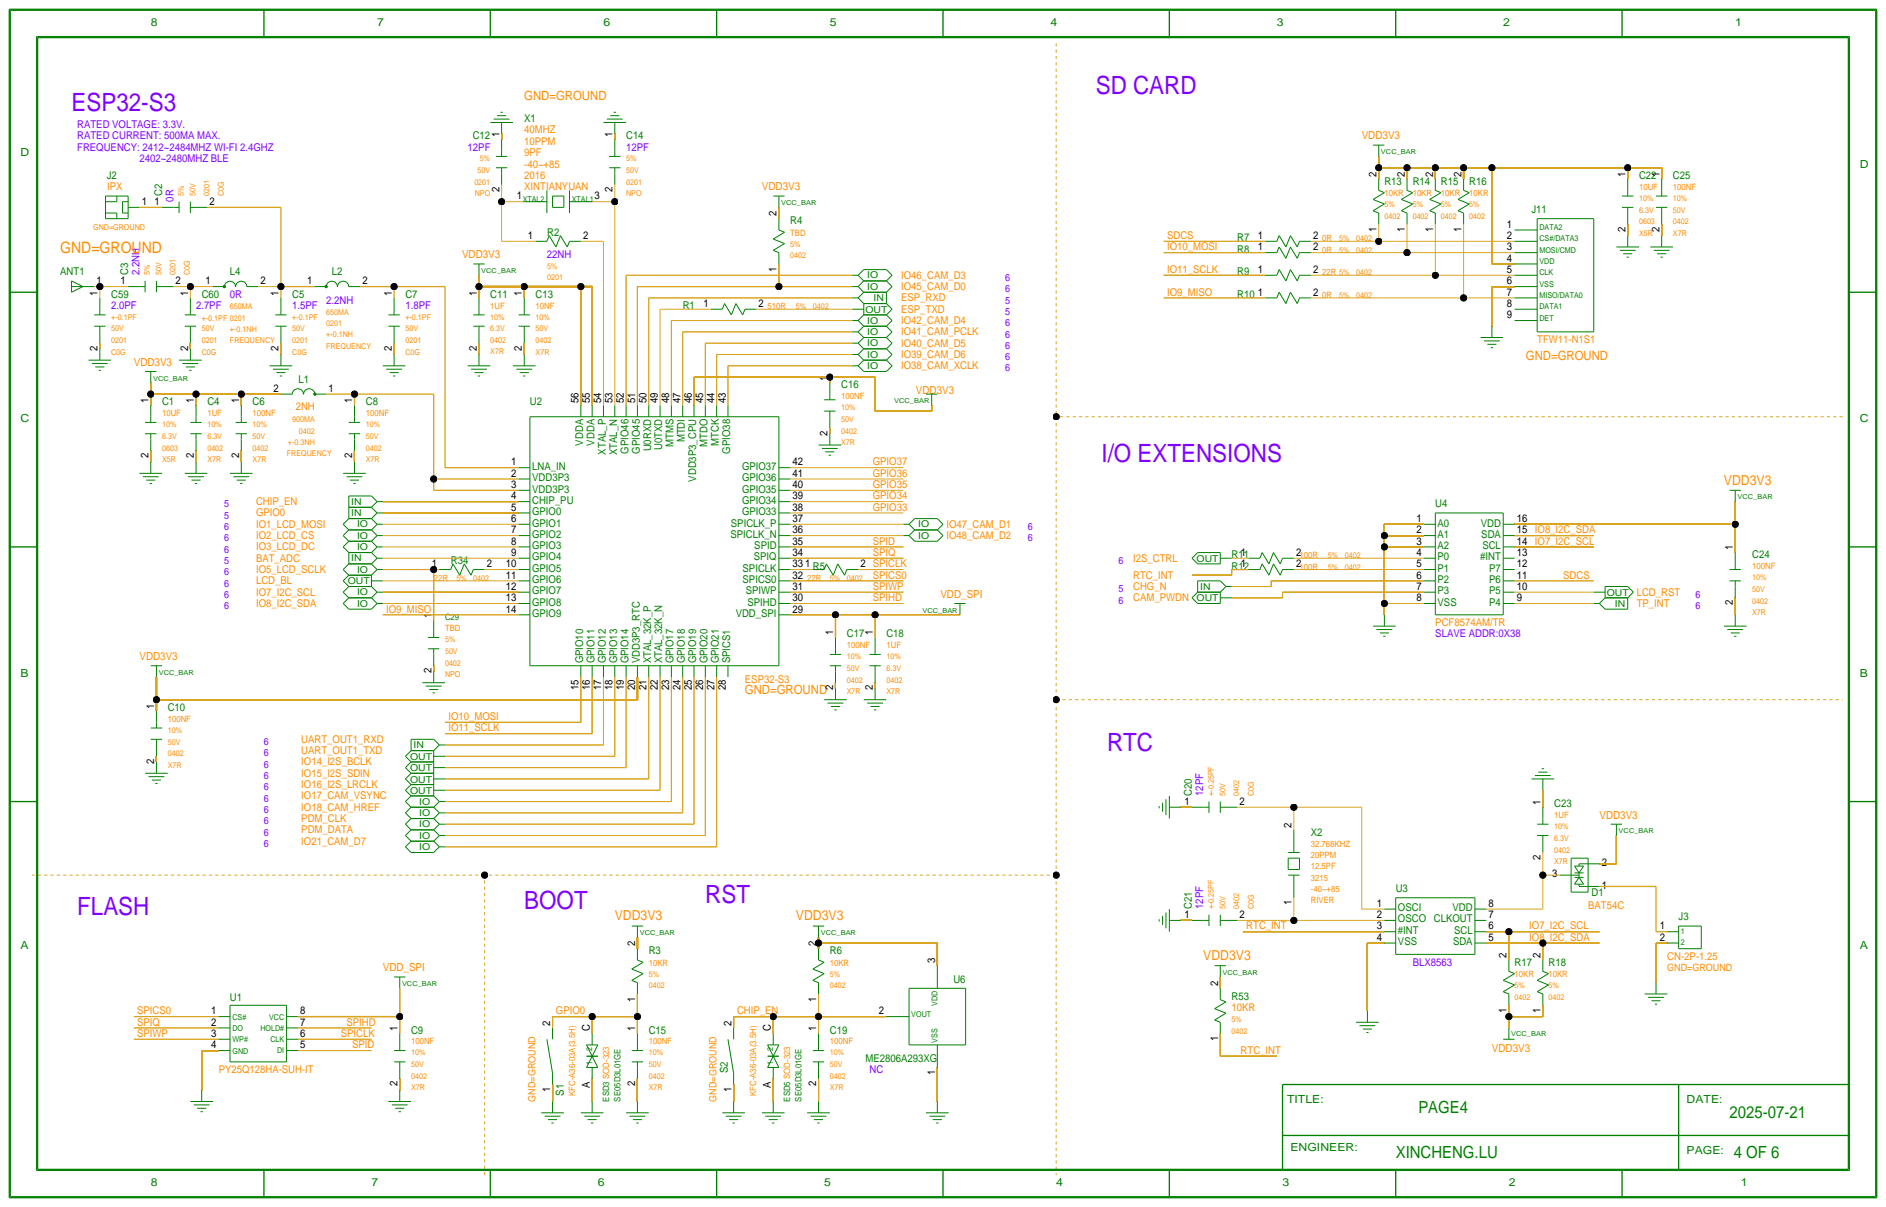
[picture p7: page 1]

2 2 | 15 15 IO8_I2C_SDA IO8_I2C_SDA
3 3 | 14 14 IO7_I2C_SCL IO7_I2C_SCL

TITLE: TITLE: PAGE4 PAGE4 | DATE: DATE: 2025-07-21 2025-07-21

ENGINEER: XINCHENG.LU | PAGE: 4 OF 6

POWER ON POWER ON VSYS VSYS VBUS VBUS | USB TO TTL / UART INPUT USB TO TTL / UART INPUT VBUS 1A VBUS 1A D3 D3 GND=GROUND GND=GROUND B5819WS B5819WS

### VBAT

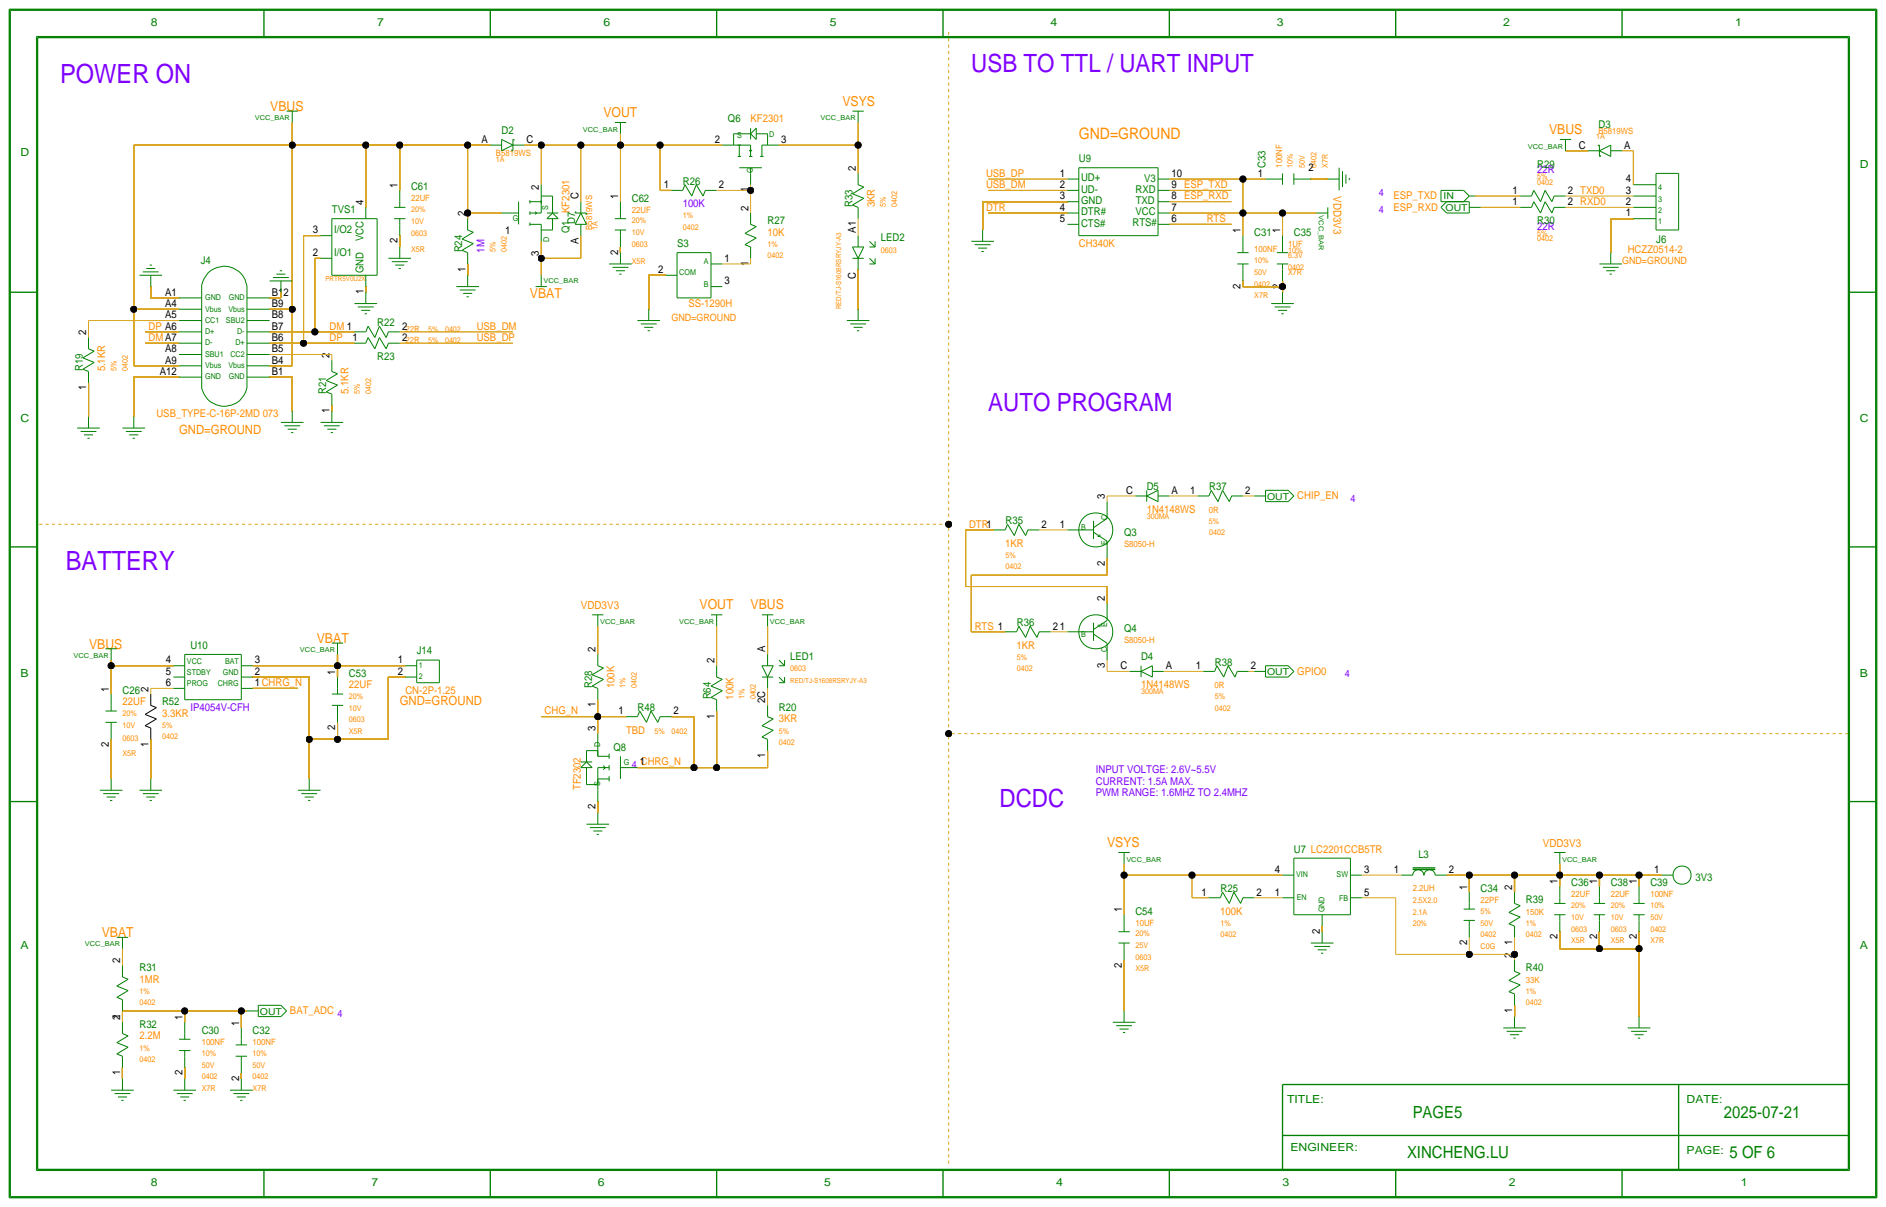
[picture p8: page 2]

TVS1

# LCD CAMERA

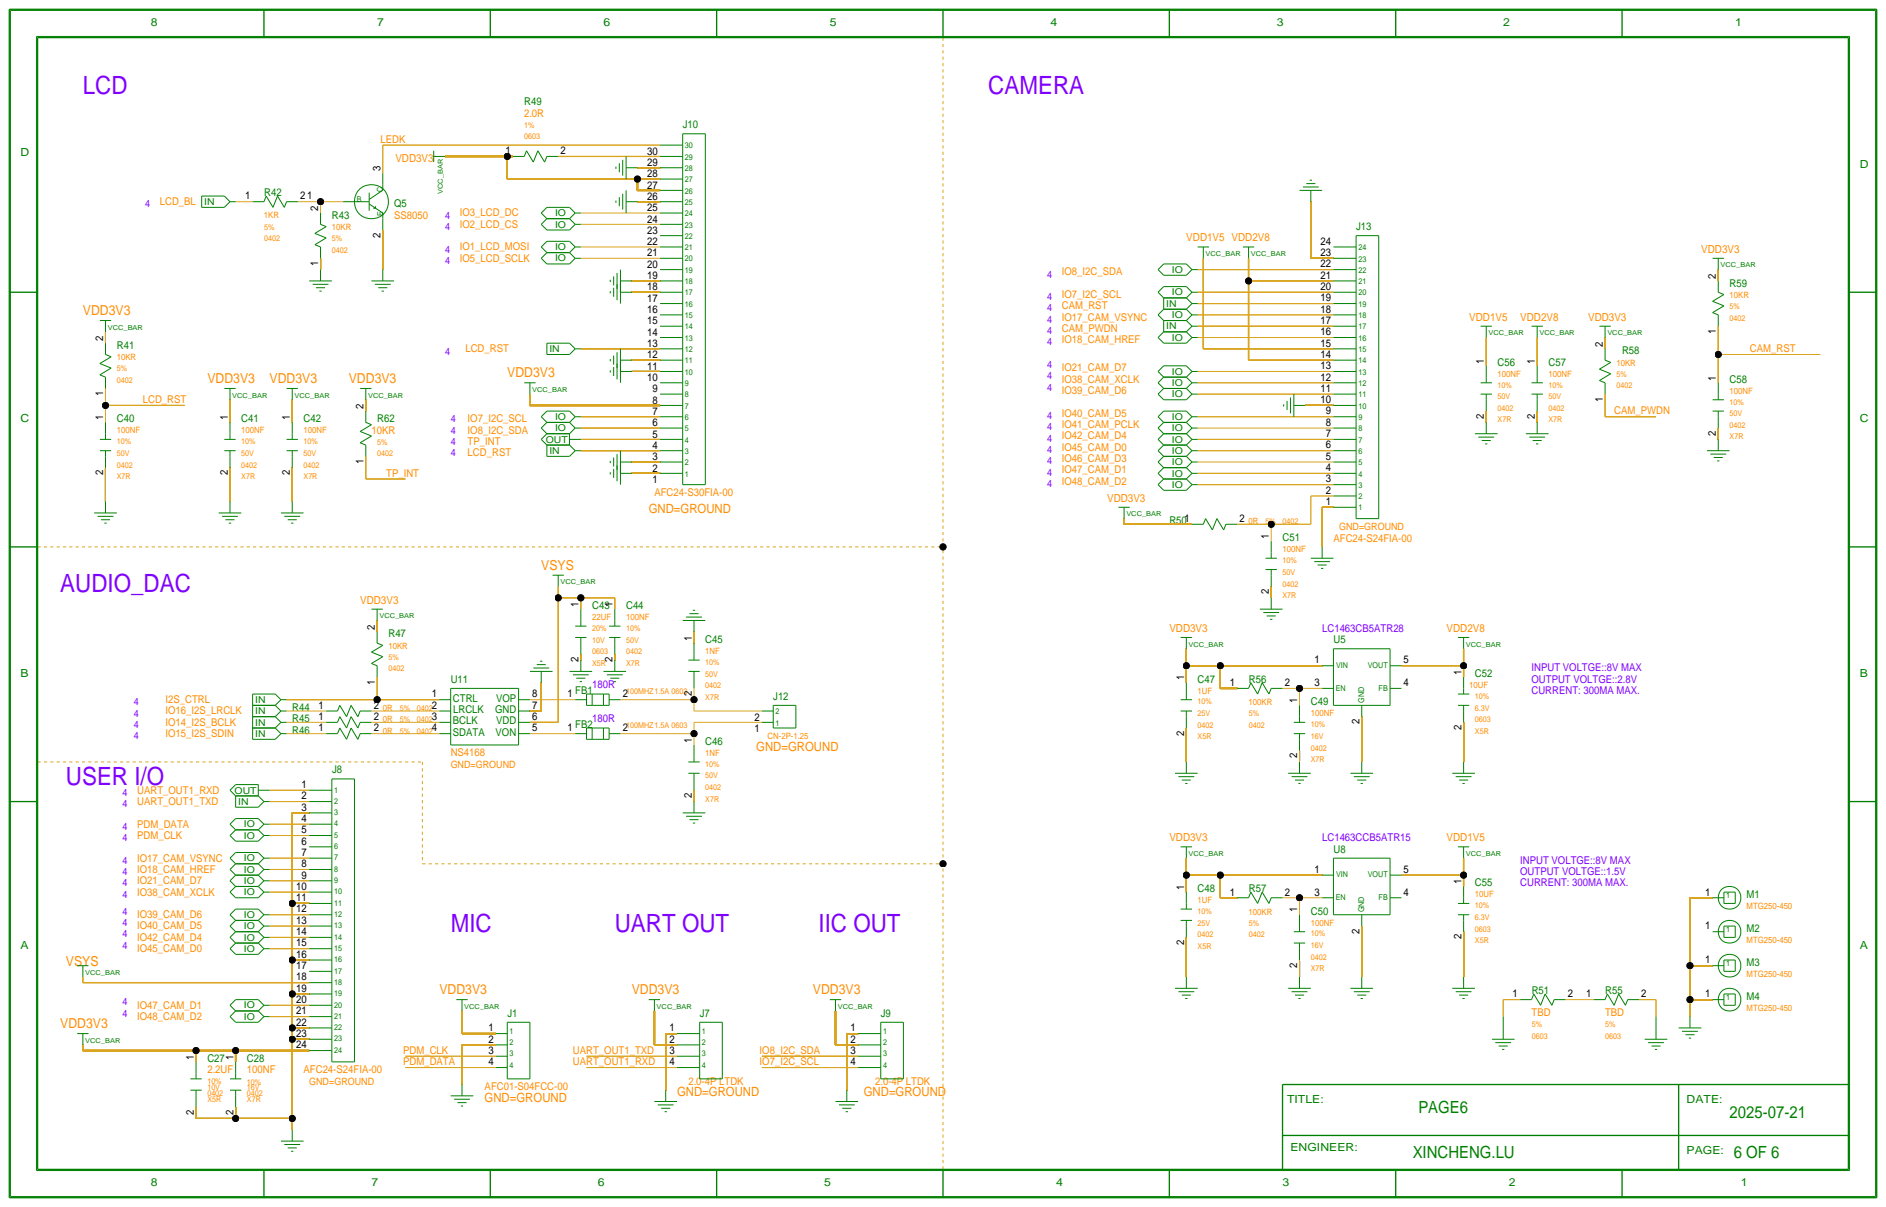
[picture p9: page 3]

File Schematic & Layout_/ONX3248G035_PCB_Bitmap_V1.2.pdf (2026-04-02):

## silkbottom

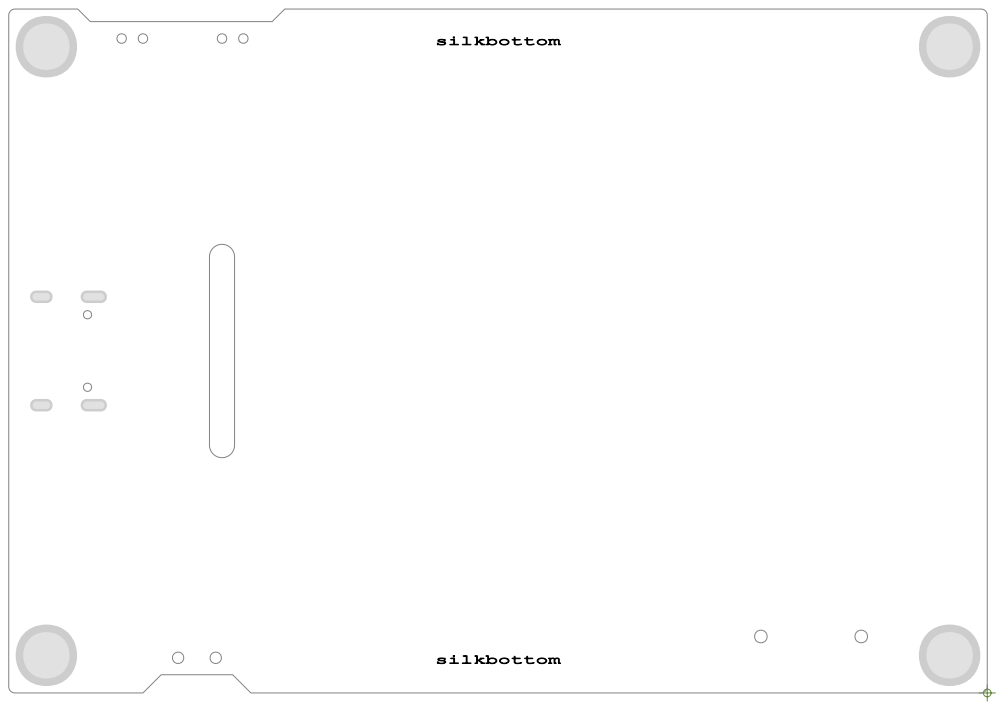
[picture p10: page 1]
silkbottom

## silktop

## CLK

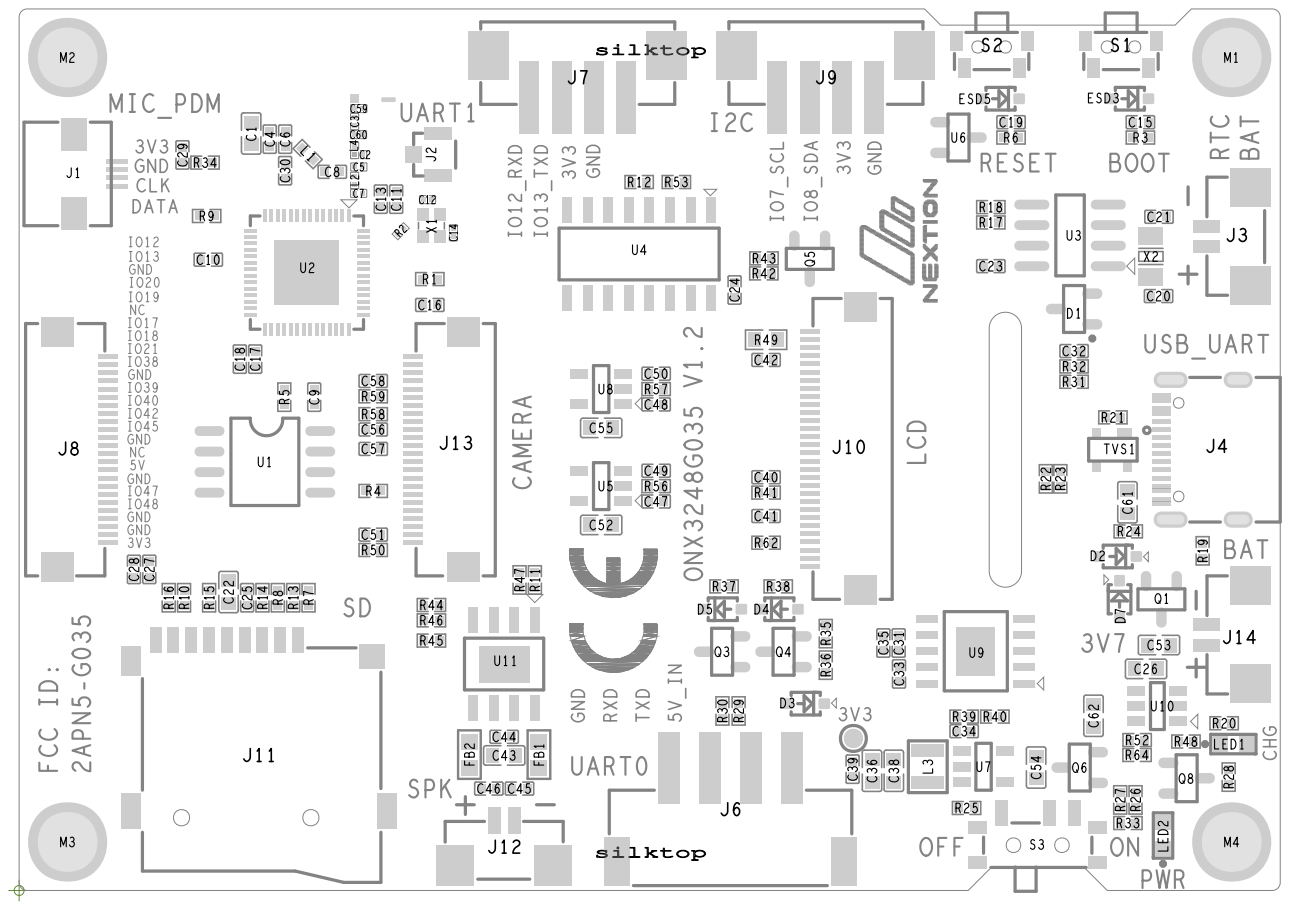
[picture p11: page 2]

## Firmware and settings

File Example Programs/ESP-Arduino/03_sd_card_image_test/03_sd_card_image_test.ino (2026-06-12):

#include <Arduino.h>
#include <Wire.h>
#include <SPI.h>
#include <SD_MMC.h>
#include <FS.h>
#include <Arduino_GFX_Library.h>
#include <Adafruit_CST8XX.h>
#include <Adafruit_PCF8574.h>
#include <jpeg_decoder.h>

#define LV_CONF_SKIP
#include <lvgl.h>
// Reuse LVGL's bundled lodepng implementation for PNG decoding. The Arduino
// sketch calls the C API directly, so the C++ wrappers are disabled here.
#define LODEPNG_NO_COMPILE_CPP
extern "C" {
#include <extra/libs/png/lodepng.h>
}

#include "BoardConfig.h"

static const uint32_t LCD_SPI_FREQ = 40000000;
static const uint16_t LVGL_BUF_LINES = 40;
static const char *IMAGE_DIR = "/images";
static const uint8_t MAX_IMAGES = 64;

// Keep the same direction macros as the touch example so the LCD and CST826
// coordinate systems stay aligned across demos.
#define DISPLAY_SWAP_XY false
#define DISPLAY_MIRROR_X true
#define DISPLAY_MIRROR_Y false

Arduino_DataBus *bus = new Arduino_HWSPI(
    LCD_DC_PIN, LCD_CS_PIN, LCD_SCLK_PIN, LCD_MOSI_PIN, LCD_MISO_PIN, &SPI, true);
Arduino_GFX *gfx = new Arduino_ST7796(bus, GFX_NOT_DEFINED, 0, false, LCD_H_RES, LCD_V_RES);

Adafruit_CST8XX touch;
Adafruit_PCF8574 ioExpander;

static lv_disp_draw_buf_t drawBuf;
static lv_disp_drv_t dispDrv;
static lv_color_t dispBuf[LCD_H_RES * LVGL_BUF_LINES];
static String images[MAX_IMAGES];
static uint8_t imageCount = 0;
static int imageIndex = 0;
static bool sdReady = false;
static bool imageBrowserMode = false;
static bool imageNeedsRedraw = false;

// Full-screen image pages are rendered into PSRAM first, then pushed to LCD in
// bands. This avoids showing top-to-bottom decode progress on the panel.
static uint16_t *frameBuf = nullptr;

static uint8_t displayRotationFromConfig() {
  bool gfxMirrorX = !DISPLAY_MIRROR_X;
  bool gfxMirrorY = DISPLAY_MIRROR_Y;
  if (!DISPLAY_SWAP_XY && !gfxMirrorX && !gfxMirrorY) return 0;
  if (DISPLAY_SWAP_XY && gfxMirrorX && !gfxMirrorY) return 1;
  if (!DISPLAY_SWAP_XY && gfxMirrorX && gfxMirrorY) return 2;
  if (DISPLAY_SWAP_XY && !gfxMirrorX && gfxMirrorY) return 3;
  if (!DISPLAY_SWAP_XY && gfxMirrorX && !gfxMirrorY) return 4;
  if (DISPLAY_SWAP_XY && gfxMirrorX && gfxMirrorY) return 5;
  if (!DISPLAY_SWAP_XY && !gfxMirrorX && gfxMirrorY) return 6;
  return 7;
}

static void setExpanderPin(uint8_t pin, bool level) {
  static uint8_t state = 0xFF;
  if (level) state |= (1 << pin);
  else state &= ~(1 << pin);
  ioExpander.digitalWriteByte(state);
}

static void lcdResetByExpander() {
  if (!ioExpander.begin(PCF8574_ADDR, &Wire)) {
    Serial.println("PCF8574 init failed");
    return;
  }
  // Keep all expander outputs high except the pins we actively drive below.
  ioExpander.digitalWriteByte(0xFF);
  delay(20);
  setExpanderPin(PCF8574_PIN_LCD_RST, false);
  delay(120);
  setExpanderPin(PCF8574_PIN_LCD_RST, true);
  delay(120);
}

static void lvglFlush(lv_disp_drv_t *drv, const lv_area_t *area, lv_color_t *colorP) {
  uint32_t width = area->x2 - area->x1 + 1;
  uint32_t height = area->y2 - area->y1 + 1;
#if (LV_COLOR_16_SWAP != 0)
  gfx->draw16bitBeRGBBitmap(area->x1, area->y1, (uint16_t *)&colorP->full, width, height);
#else
  gfx->draw16bitRGBBitmap(area->x1, area->y1, (uint16_t *)&colorP->full, width, height);
#endif
  lv_disp_flush_ready(drv);
}

static void lvglTouchRead(lv_indev_drv_t *, lv_indev_data_t *data) {
  static int16_t lastX = 0;
  static int16_t lastY = 0;
  if (touch.touched()) {
    CST_TS_Point point = touch.getPoint();
    lastX = constrain(point.x, 0, (int16_t)gfx->width() - 1);
    lastY = constrain(point.y, 0, (int16_t)gfx->height() - 1);
    data->state = LV_INDEV_STATE_PR;
  } else {
    data->state = LV_INDEV_STATE_REL;
  }
  data->point.x = lastX;
  data->point.y = lastY;
}

static void lvglBegin() {
  // LVGL is still used for the no-card / no-image prompt pages. The image
  // browser draws directly to the LCD after a full frame has been decoded.
  lv_init();
  lv_disp_draw_buf_init(&drawBuf, dispBuf, nullptr, LCD_H_RES * LVGL_BUF_LINES);
  lv_disp_drv_init(&dispDrv);
  dispDrv.hor_res = gfx->width();
  dispDrv.ver_res = gfx->height();
  dispDrv.flush_cb = lvglFlush;
  dispDrv.draw_buf = &drawBuf;
  lv_disp_drv_register(&dispDrv);
  static lv_indev_drv_t indevDrv;
  lv_indev_drv_init(&indevDrv);
  indevDrv.type = LV_INDEV_TYPE_POINTER;
  indevDrv.read_cb = lvglTouchRead;
  lv_indev_drv_register(&indevDrv);
}

static void boardBegin() {
  Serial.begin(115200);
  delay(500);
  Serial.println("\nONX3248G035 Arduino 03_sd_card_image_test");
  Wire.begin(NEXTION_IIC_SDA_PIN, NEXTION_IIC_SCL_PIN, 400000);
  lcdResetByExpander();
  gfx->begin(LCD_SPI_FREQ);
  gfx->setRotation(displayRotationFromConfig());
  gfx->fillScreen(RGB565_WHITE);
  pinMode(LCD_BL_PIN, OUTPUT);
  digitalWrite(LCD_BL_PIN, HIGH);
  touch.begin(&Wire, CST826_ADDR);
  lvglBegin();
}

static bool mountSdCard() {
  setExpanderPin(PCF8574_PIN_SDCS, true);
  SD_MMC.setPins(SD_CLK_PIN, SD_CMD_PIN, SD_D0_PIN);
  sdReady = SD_MMC.begin("/sdcard", true, false, SDMMC_FREQ_DEFAULT);
  return sdReady;
}

static bool endsWithIgnoreCase(const String &value, const char *suffix) {
  String lower = value;
  lower.toLowerCase();
  return lower.endsWith(suffix);
}

static bool isImageFile(const String &name) {
  return endsWithIgnoreCase(name, ".jpg") || endsWithIgnoreCase(name, ".jpeg") ||
         endsWithIgnoreCase(name, ".png") || endsWithIgnoreCase(name, ".bmp") ||
         endsWithIgnoreCase(name, ".bin") || endsWithIgnoreCase(name, ".qoi") ||
         endsWithIgnoreCase(name, ".sjpg") || endsWithIgnoreCase(name, ".spng") ||
         endsWithIgnoreCase(name, ".sqoi");
}

static String baseNameOf(const char *path) {
  String name(path);
  int slash = name.lastIndexOf('/');
  if (slash >= 0) name = name.substring(slash + 1);
  return name;
}

static String imagePathAt(int index) {
  return String(IMAGE_DIR) + "/" + images[index];
}

static void sortImages() {
  for (uint8_t i = 0; i + 1 < imageCount; ++i) {
    for (uint8_t j = i + 1; j < imageCount; ++j) {
      String a = images[i];
      String b = images[j];
      a.toLowerCase();
      b.toLowerCase();
      if (a > b) {
        String tmp = images[i];
        images[i] = images[j];
        images[j] = tmp;
      }
    }
  }
}

static bool isJpegFile(const String &name) {
  return endsWithIgnoreCase(name, ".jpg") || endsWithIgnoreCase(name, ".jpeg") ||
         endsWithIgnoreCase(name, ".sjpg");
}

static bool isPngFile(const String &name) {
  return endsWithIgnoreCase(name, ".png") || endsWithIgnoreCase(name, ".spng");
}

static void showCenteredMessage(const char *message, uint32_t color = RGB565_RED) {
  gfx->fillScreen(RGB565_BLACK);
  gfx->setTextColor(color);
  gfx->setTextSize(2);
  gfx->setCursor(18, gfx->height() / 2 - 24);
  gfx->println(message);
}

static bool ensureFrameBuffer() {
  if (frameBuf) return true;
  frameBuf = static_cast<uint16_t *>(ps_malloc(gfx->width() * gfx->height() * sizeof(uint16_t)));
  if (!frameBuf) {
    Serial.println("Frame buffer allocation failed");
    return false;
  }
  return true;
}

static void clearFrameBuffer(uint16_t color) {
  if (!frameBuf) return;
  uint32_t pixels = gfx->width() * gfx->height();
  for (uint32_t i = 0; i < pixels; ++i) {
    frameBuf[i] = color;
  }
}

static void presentFrameBuffer() {
  if (!frameBuf) return;
  // Arduino_GFX transfers are split into moderate bands to keep SPI writes
  // stable while still updating the finished frame quickly.
  const int16_t linesPerFlush = 40;
  for (int16_t y = 0; y < gfx->height(); y += linesPerFlush) {
    int16_t h = min<int16_t>(linesPerFlush, gfx->height() - y);
    gfx->draw16bitBeRGBBitmap(0, y, frameBuf + y * gfx->width(), gfx->width(), h);
  }
}

static uint16_t rgb565BigEndian(uint8_t r, uint8_t g, uint8_t b) {
  // draw16bitBeRGBBitmap expects RGB565 bytes in big-endian order.
  uint16_t rgb565 = ((uint16_t)(r & 0xF8) << 8) | ((uint16_t)(g & 0xFC) << 3) | (b >> 3);
  return (uint16_t)((rgb565 << 8) | (rgb565 >> 8));
}

static void drawScaledRgb565Be(const uint16_t *src, uint16_t srcW, uint16_t srcH) {
  if (!src || srcW == 0 || srcH == 0 || !frameBuf) return;

  // Match the verified behavior on hardware: scale every image to screen width
  // and center it vertically when the aspect ratio leaves unused space.
  uint16_t dstW = gfx->width();
  uint32_t scaledH32 = ((uint32_t)srcH * dstW + srcW / 2) / srcW;
  uint16_t dstH = min<uint32_t>(scaledH32, gfx->height());
  int16_t dstX = 0;
  int16_t dstY = (gfx->height() - dstH) / 2;

  for (uint16_t y = 0; y < dstH; ++y) {
    uint32_t srcY = ((uint32_t)y * srcH) / dstH;
    uint16_t *dst = frameBuf + (dstY + y) * gfx->width() + dstX;
    const uint16_t *srcRow = src + srcY * srcW;
    for (uint16_t x = 0; x < dstW; ++x) {
      uint32_t srcX = ((uint32_t)x * srcW) / dstW;
      dst[x] = srcRow[srcX];
    }
  }
}

static void drawScaledRgbaLvgl(const uint8_t *rgba, uint16_t srcW, uint16_t srcH) {
  if (!rgba || srcW == 0 || srcH == 0 || !frameBuf) return;

  // lodepng is compiled through LVGL on this target, whose 32-bit color layout
  // is BGRA in memory. Alpha is composited over the white screen background.
  uint16_t dstW = gfx->width();
  uint32_t scaledH32 = ((uint32_t)srcH * dstW + srcW / 2) / srcW;
  uint16_t dstH = min<uint32_t>(scaledH32, gfx->height());
  int16_t dstX = 0;
  int16_t dstY = (gfx->height() - dstH) / 2;

  for (uint16_t y = 0; y < dstH; ++y) {
    uint32_t srcY = ((uint32_t)y * srcH) / dstH;
    uint16_t *dst = frameBuf + (dstY + y) * gfx->width() + dstX;
    const uint8_t *srcRow = rgba + srcY * srcW * 4;
    for (uint16_t x = 0; x < dstW; ++x) {
      uint32_t srcX = ((uint32_t)x * srcW) / dstW;
      const uint8_t *px = srcRow + srcX * 4;

      uint8_t b = px[0];
      uint8_t g = px[1];
      uint8_t r = px[2];
      uint8_t a = px[3];
      if (a < 255) {
        r = ((uint16_t)r * a + 255U * (255U - a)) / 255U;
        g = ((uint16_t)g * a + 255U * (255U - a)) / 255U;
        b = ((uint16_t)b * a + 255U * (255U - a)) / 255U;
      }
      dst[x] = rgb565BigEndian(r, g, b);
    }
  }
}

static bool readWholeFile(const String &path, uint8_t **data, size_t *size) {
  *data = nullptr;
  *size = 0;

  File file = SD_MMC.open(path, FILE_READ);
  if (!file) return false;

  size_t fileSize = file.size();
  uint8_t *buffer = static_cast<uint8_t *>(ps_malloc(fileSize));
  if (!buffer) {
    file.close();
    return false;
  }

  size_t bytesRead = file.read(buffer, fileSize);
  file.close();
  if (bytesRead != fileSize) {
    free(buffer);
    return false;
  }

  *data = buffer;
  *size = fileSize;
  return true;
}

static bool drawJpegImage(const String &path) {
  uint8_t *jpegData = nullptr;
  size_t jpegSize = 0;
  if (!readWholeFile(path, &jpegData, &jpegSize)) return false;

  esp_jpeg_image_cfg_t infoCfg = {};
  infoCfg.indata = jpegData;
  infoCfg.indata_size = jpegSize;
  infoCfg.out_format = JPEG_IMAGE_FORMAT_RGB565;
  infoCfg.out_scale = JPEG_IMAGE_SCALE_0;

  esp_jpeg_image_output_t originalInfo = {};
  esp_err_t err = esp_jpeg_get_image_info(&infoCfg, &originalInfo);
  if (err != ESP_OK) {
    Serial.printf("esp_jpeg_get_image_info failed: 0x%x\r\n", (unsigned)err);
    free(jpegData);
    return false;
  }

  // Decode at original resolution, then use one common scaler for JPEG and PNG.
  // This keeps same-size images visually consistent on the 320x480 display.
  esp_jpeg_image_cfg_t decodeCfg = infoCfg;
  decodeCfg.out_scale = JPEG_IMAGE_SCALE_0;
  decodeCfg.flags.swap_color_bytes = 1;

  esp_jpeg_image_output_t scaledInfo = {};
  err = esp_jpeg_get_image_info(&decodeCfg, &scaledInfo);
  if (err != ESP_OK) {
    Serial.printf("esp_jpeg_get_scaled_info failed: 0x%x\r\n", (unsigned)err);
    free(jpegData);
    return false;
  }

  uint16_t *decoded = static_cast<uint16_t *>(ps_malloc(scaledInfo.output_len));
  if (!decoded) {
    free(jpegData);
    return false;
  }

  decodeCfg.outbuf = reinterpret_cast<uint8_t *>(decoded);
  decodeCfg.outbuf_size = scaledInfo.output_len;

  err = esp_jpeg_decode(&decodeCfg, &scaledInfo);
  free(jpegData);
  if (err != ESP_OK) {
    Serial.printf("esp_jpeg_decode failed: 0x%x\r\n", (unsigned)err);
    free(decoded);
    return false;
  }

  Serial.printf("JPEG decoded: original=%ux%u scaled=%ux%u scale=%u len=%u\r\n",
                originalInfo.width, originalInfo.height, scaledInfo.width, scaledInfo.height,
                (unsigned)decodeCfg.out_scale, (unsigned)scaledInfo.output_len);
  drawScaledRgb565Be(decoded, scaledInfo.width, scaledInfo.height);
  free(decoded);
  return true;
}

static bool drawPngImage(const String &path) {
  uint8_t *pngData = nullptr;
  size_t pngSize = 0;
  if (!readWholeFile(path, &pngData, &pngSize)) {
    Serial.printf("PNG read failed: %s\r\n", path.c_str());
    return false;
  }

  unsigned char *rgba = nullptr;
  unsigned pngW = 0;
  unsigned pngH = 0;
  // lodepng allocates the output buffer through LVGL memory because
  // LV_MEM_CUSTOM is enabled in build_opt.h.
  unsigned err = lodepng_decode32(&rgba, &pngW, &pngH, pngData, pngSize);
  free(pngData);

  if (err != 0 || !rgba) {
    Serial.printf("lodepng_decode32 failed: err=%u\r\n", err);
    return false;
  }

  Serial.printf("PNG decoded: %ux%u len=%u\r\n", pngW, pngH, (unsigned)(pngW * pngH * 4));

  drawScaledRgbaLvgl(rgba, pngW, pngH);

  lv_mem_free(rgba);
  return true;
}

static void drawCurrentImage() {
  if (imageCount == 0) return;
  if (!ensureFrameBuffer()) {
    showCenteredMessage("No PSRAM frame buffer");
    return;
  }

  String path = imagePathAt(imageIndex);
  Serial.printf("Show image %d/%u: %s, mode=WIDTH_FIT\r\n",
                imageIndex + 1, imageCount, path.c_str());

  clearFrameBuffer(RGB565_BLACK);
  bool ok = false;
  if (isJpegFile(images[imageIndex])) {
    ok = drawJpegImage(path);
  } else if (isPngFile(images[imageIndex])) {
    ok = drawPngImage(path);
  }

  if (ok) {
    presentFrameBuffer();
  } else {
    showCenteredMessage("Image decode failed");
  }
}

static void nextImage(int delta) {
  if (imageCount == 0) return;
  imageIndex = (imageIndex + delta + imageCount) % imageCount;
  imageNeedsRedraw = true;
}

static void pollImageTouch() {
  static bool wasPressed = false;
  static int16_t startX = 0;
  static int16_t startY = 0;
  static int16_t lastX = 0;
  static int16_t lastY = 0;

  bool pressed = touch.touched();
  if (pressed) {
    CST_TS_Point point = touch.getPoint();
    lastX = constrain(point.x, 0, (int16_t)gfx->width() - 1);
    lastY = constrain(point.y, 0, (int16_t)gfx->height() - 1);
    if (!wasPressed) {
      startX = lastX;
      startY = lastY;
      wasPressed = true;
    }
    return;
  }

  if (!wasPressed) return;
  wasPressed = false;

  int16_t dx = lastX - startX;
  int16_t dy = lastY - startY;

  if (abs(dx) > 60 && abs(dx) > abs(dy)) {
    nextImage(dx < 0 ? 1 : -1);
  }
}

static bool isImageFile(const char *name) {
  String lower(name);
  lower.toLowerCase();
  return isImageFile(lower);
}

static void scanImages() {
  imageCount = 0;
  if (!sdReady) return;
  File dir = SD_MMC.open(IMAGE_DIR);
  if (!dir || !dir.isDirectory()) return;
  for (File f = dir.openNextFile(); f && imageCount < MAX_IMAGES; f = dir.openNextFile()) {
    String name = baseNameOf(f.name());
    if (!f.isDirectory() && isImageFile(name)) {
      images[imageCount++] = name;
    }
    f.close();
  }
  sortImages();
}

static void buildUi() {
  lv_obj_t *scr = lv_scr_act();
  lv_obj_clean(scr);
  lv_obj_clear_flag(scr, LV_OBJ_FLAG_SCROLLABLE);

  if (!sdReady) {
    lv_obj_set_style_bg_color(scr, lv_color_white(), 0);
    lv_obj_t *label = lv_label_create(scr);
    lv_obj_set_width(label, 250);
    lv_obj_set_style_text_align(label, LV_TEXT_ALIGN_CENTER, 0);
    lv_obj_set_style_text_color(label, lv_color_hex(0xff0000), 0);
    lv_label_set_text(label, " No SD card detected. Please insert it and then power on again.");
    lv_obj_align(label, LV_ALIGN_CENTER, 0, 0);
  } else if (imageCount == 0) {
    lv_obj_set_style_bg_color(scr, lv_color_white(), 0);
    lv_obj_t *label = lv_label_create(scr);
    lv_label_set_recolor(label, true);
    lv_label_set_text(label, "#ff0000  Image not found. #");
    lv_obj_align(label, LV_ALIGN_CENTER, 0, 0);
  } else {
    // Image pixels are drawn directly from the PSRAM frame buffer. Avoid LVGL
    // refreshes over the image page, otherwise LVGL can overwrite the LCD.
    imageBrowserMode = true;
    imageNeedsRedraw = true;
  }
}

void setup() {
  boardBegin();
  mountSdCard();
  scanImages();
  buildUi();
  if (!imageBrowserMode) lv_timer_handler();
  if (imageNeedsRedraw) {
    imageNeedsRedraw = false;
    drawCurrentImage();
  }
}

void loop() {
  static uint32_t lastMs = millis();
  uint32_t now = millis();
  lv_tick_inc(now - lastMs);
  lastMs = now;
  if (imageBrowserMode) {
    pollImageTouch();
  } else {
    lv_timer_handler();
  }
  if (imageNeedsRedraw) {
    imageNeedsRedraw = false;
    drawCurrentImage();
  }
  delay(5);
}

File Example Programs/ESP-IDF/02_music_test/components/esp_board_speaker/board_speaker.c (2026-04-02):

/**
 * @file board_speaker.c
 * @brief Hardware Driver for NS4168 Speaker Amplifier (ESP32 I2S Interface)
 * @details Implements speaker subsystem initialization, power control (on/off), and audio playback
 *          via ESP32 standard I2S driver. Uses PCF8574 I2C GPIO expander to control the amplifier enable pin,
 *          and configures I2S master TX channel for 16-bit stereo audio output to NS4168 codec.
 * @note Critical Dependencies:
 *       - driver/i2s_std.h: ESP32 standard I2S peripheral driver
 *       - exio_pcf8574.h: PCF8574 I2C GPIO expander driver (I2S_CTRL pin control)
 *       - board_speaker.h: Hardware pin definitions (BCLK/WS/SDATA for NS4168)
 *       - I2S_FRE: Predefined I2S sample rate (e.g., 44100/48000 Hz)
 * @version 1.0
 * @date 2025
 */

#include "driver/i2s_std.h"
#include "driver/gpio.h"
#include "esp_err.h"
#include "exio_pcf8574.h"
#include "board_speaker.h"
#include "exio_pcf8574.h"

/* For memset() */
#include <string.h>

/* -------------------------------------------------------------------------- */
/* Static Module Variables (Private)                                          */
/* -------------------------------------------------------------------------- */

/** @brief I2S transmit channel handle (master TX role for audio output to NS4168) */
static i2s_chan_handle_t tx_handle;

/** @brief Speaker power state flag (true = amplifier/I2S enabled, false = disabled) */
static bool  Speaker_state = false;

/* Cached PCM format for silence flush helpers.
 * This is a SOFTWARE-side cache for helper utilities; it does not automatically
 * reconfigure I2S hardware clock/slot.
 */
static uint32_t s_pcm_rate_hz  = I2S_FRE;
static uint8_t  s_pcm_bits     = 16U;
static uint8_t  s_pcm_channels = 2U;

/**
 * @brief Update cached PCM format (used by helper utilities)
 * @note This does NOT reconfigure I2S hardware. If you want hardware to follow
 *       the new sample rate/bit width, do it elsewhere.
 */
void speaker_set_pcm_format(uint32_t rate_hz, uint32_t bits_cfg, uint8_t channels)
{
    if (rate_hz != 0U) {
        s_pcm_rate_hz = rate_hz;
    }

    /* bits_cfg is typically 16 or 32 */
    s_pcm_bits = (bits_cfg == 32U) ? 32U : 16U;

    /* channels: 1=mono, 2=stereo */
    s_pcm_channels = (channels == 1U) ? 1U : 2U;
}

/**
 * @brief Flush a short period of SILENCE (zeros) into I2S DMA.
 * @details Useful when the audio pipeline is paused and no longer calling
 *          write callbacks, but you still want to park I2S output at 0 to
 *          avoid click/pop when restarting or switching tracks.
 *
 *          This bypasses Speaker_state gating on purpose: amplifier can be
 *          on or off; we just want I2S DMA to contain zeros.
 */
void speaker_flush_silence_ms(uint32_t ms)
{
    if (!tx_handle || ms == 0U) {
        return;
    }

    uint32_t rate = (s_pcm_rate_hz != 0U) ? s_pcm_rate_hz : I2S_FRE;
    uint32_t frames = (uint32_t)(((uint64_t)rate * (uint64_t)ms) / 1000ULL);
    if (frames == 0U) {
        frames = 1U;
    }

    uint32_t ch  = (s_pcm_channels == 1U) ? 1U : 2U;
    uint32_t bps = (s_pcm_bits == 32U) ? 4U : 2U; /* bytes per sample */
    uint32_t bytes_per_frame = ch * bps;
    uint64_t total = (uint64_t)frames * (uint64_t)bytes_per_frame;

    static uint8_t zeros[256];
    memset(zeros, 0, sizeof(zeros));

    while (total > 0ULL) {
        size_t chunk = (total > sizeof(zeros)) ? sizeof(zeros) : (size_t)total;
        /* Align chunk to whole frames */
        chunk -= (chunk % bytes_per_frame);
        if (chunk == 0U) {
            chunk = bytes_per_frame;
        }

        size_t written = 0;
        (void)i2s_channel_write(tx_handle, zeros, chunk, &written, 20);

        if (written == 0U) {
            total -= chunk;
        } else {
            total -= written;
        }
    }
}

/* -------------------------------------------------------------------------- */
/* Public Speaker Driver Functions (API)                                      */
/* -------------------------------------------------------------------------- */
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

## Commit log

2026-04-02 init repository
    [ONX3248G035_2D_File.dwg, partitions.csv]
2026-06-12 Add ESP-Arduino examples and update README
